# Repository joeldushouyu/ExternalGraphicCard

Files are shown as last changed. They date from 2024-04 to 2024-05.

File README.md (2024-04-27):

# ExternalGraphicCard

This Github repo contain the documentation for the USB-To-HDMI adapter(External Graphic Card) that I designed for my Senior Project.



The __USB To HDMI Adapter__(External Graphic Card) is an attempt to reproduce device that is similar to Startech's [USB32HD4k](https://www.startech.com/en-us/display-video-adapters/usb32hd4k) device that works on Linux, Ubuntu specifically. 

Currently, the device support video streaming up to 1080p at 30HZ. 

The device is compatible to most linux distribution that support by [evdi](https://github.com/DisplayLink/evdi). Currently, the device is tested and verified on Ubuntu 20.04.

When plugging the USb 3.0 Device into the host laptop and launch the C++ program, a new display monitor will be registered in OS and image data will stream out from the USb 3.0 port to the FPGA and output in HDMI signal.

**For more info**, please refer to the [user manual](Usermanual.md), [Technical Manual](TechnicalMaunaul.md), and the [Fabrication Plan Manual](./FabricationMaunal.md)

# Demonstration

## Video & Sound in Sync
[Video link](https://github.com/joeldushouyu/ExternalGraphicCard/blob/main/videoDirectory/video-sync.mp4)



## Drag window across monitors
[Video link](https://github.com/joeldushouyu/ExternalGraphicCard/blob/main/videoDirectory/drag-window-between-monitors.mp4)



## Browing  website
[Video link](https://github.com/joeldushouyu/ExternalGraphicCard/blob/main/videoDirectory/browsing-website.mp4)

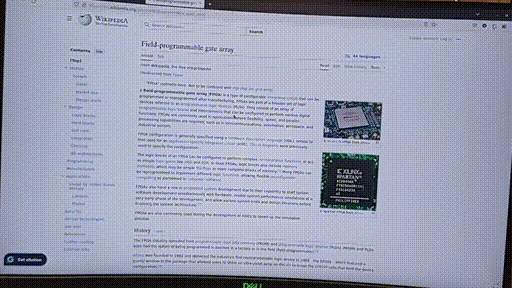
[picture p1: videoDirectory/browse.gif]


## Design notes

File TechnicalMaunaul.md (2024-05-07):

# Theory of Operation

### Figure 1: Concept Diagram
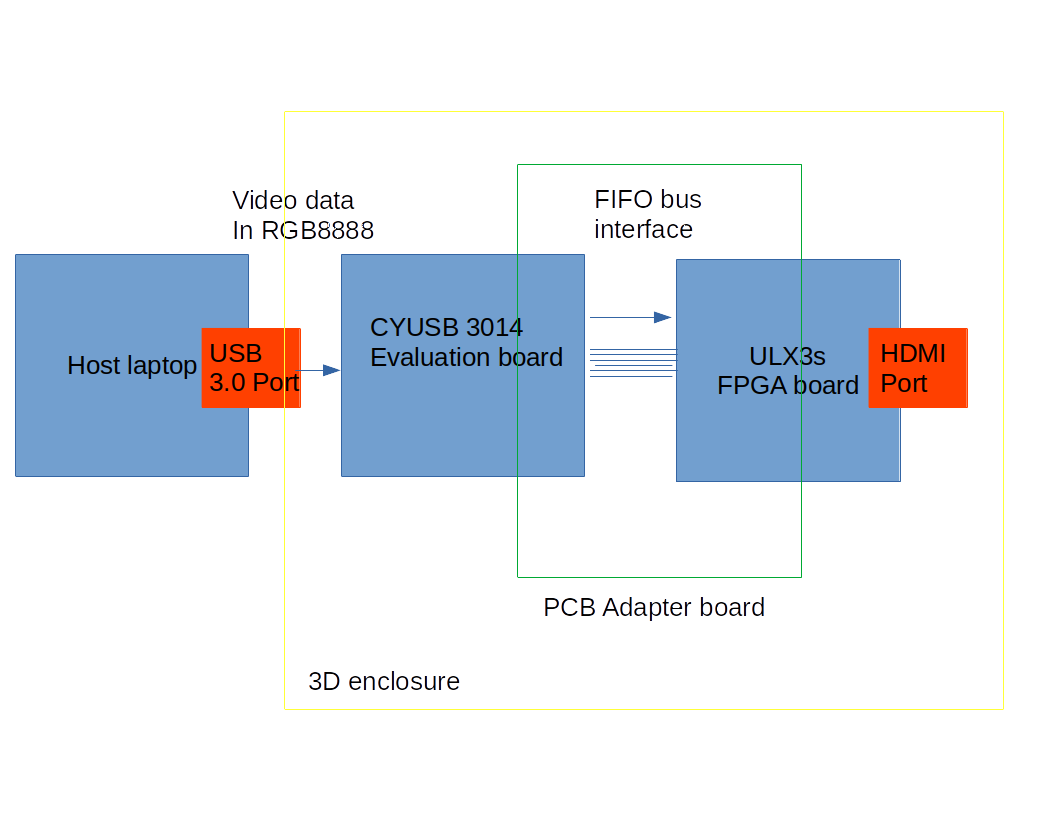
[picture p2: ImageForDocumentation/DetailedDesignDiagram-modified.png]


The device consists of 3 Major components, the __C++ program__ on the host laptop, the __CYUSB 3014 Evaluation board__, and __ULX3s__.

### C++ program on the host laptop
The C++ program on the laptop is mainly responsible for interacting with the OS to create a virtualized screen and transmit video data through USB 3.0 protocol to the CYUSB3014 device. Notably, DisplayLink, a company that sells existing USB-to-HDMI display adapters, has open-sourced part of their code to the public on Github, the [evdi](https://github.com/DisplayLink/evdi) repo. The project provides detailed documentation on their API. In addition, the repo contains a C++ based python-binding test program. 

### CYUSB3014 Device

The CyUSB3014 Device is an [evaluation board](https://www.infineon.com/cms/en/product/evaluation-boards/cyusb3kit-003/) produced by Infineon Technologies. The evaluation board consists of a CYUSB3014 programmable IC, which supports USB 3.0 communication protocol and provides a Slave Fifo Interface that allows FPGA/micro-controllers to read and write data to the fifo to interact between the USB 3.0 host device.  

 **Note**: for more information regarding the configuration below, please refer to [An65974](./ReferenceDataSheet/Infineon-AN65974_Designing_with_the_EZ-USB_FX3_Slave_FIFO_Interface-ApplicationNotes-v17_00-EN.pdf) document from Infineon Technologies. 

### Figure 2: Synchronous slave Fifo interface 
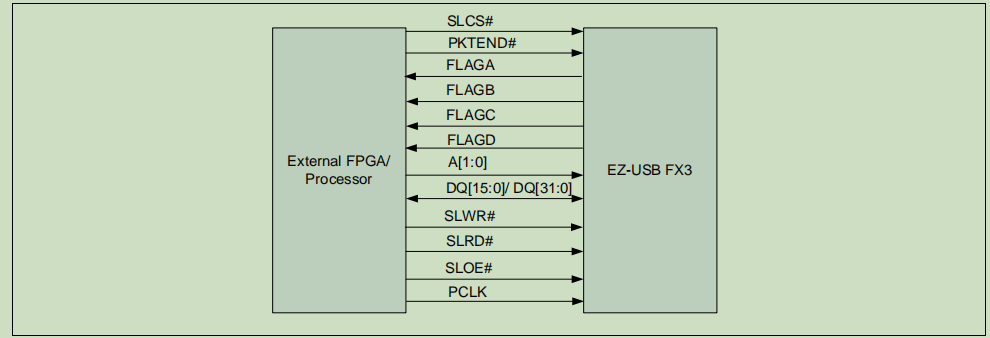
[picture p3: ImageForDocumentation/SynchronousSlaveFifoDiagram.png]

The [An65974](./ReferenceDataSheet/Infineon-AN65974_Designing_with_the_EZ-USB_FX3_Slave_FIFO_Interface-ApplicationNotes-v17_00-EN.pdf) document provides the Synchronous slave FIFO between External FPGA, as shown in Figure 2. 

In Figure 2, SLCS, SLWR, SLRD, SLOE, PKTEND, and A[1:0] are the combination of signal wires that are used by FPGA to control whether it wants to read or write to the FIFO on CyUSB3014. The PCLK is the slave FIFO interface clock from the FPGA to CyUSB3014 device, which supports up to 100MHZ. Thus, the synchronous slave FIFO mode theoretically supports up to 320Mbit/s transfer rate. For a faster transfer rate, please refer to the async fifo mode of CyUSB3014.

Moreover, FLAGA, FLAGB, FLAGC, and FLAGD are flag outputs from CyUSB3014 to indicate whether the FIFO is full/empty, or almost full/empty to FPGA. 

### ULX3s

The ULX3s is an open-sourced ECP5 [FPGA board](https://radiona.org/ulx3s/) designed by Radiona. The Ulx3s board is built around the Lattice Semiconductor ECP5-series FPGA chip and is fully supported by the latest open-source toolchains. The board consists of 56 pins (28 differential pairs), 2 USB 2.0 ports, 11 LEDs, and a Digital video (GPDI General-purpose Differential Interface). For more detail regarding to the board, please refer to the [information](https://www.crowdsupply.com/radiona/ulx3s) on CrowSupply.

## How it all work together

### Figure 3 Verilog Design
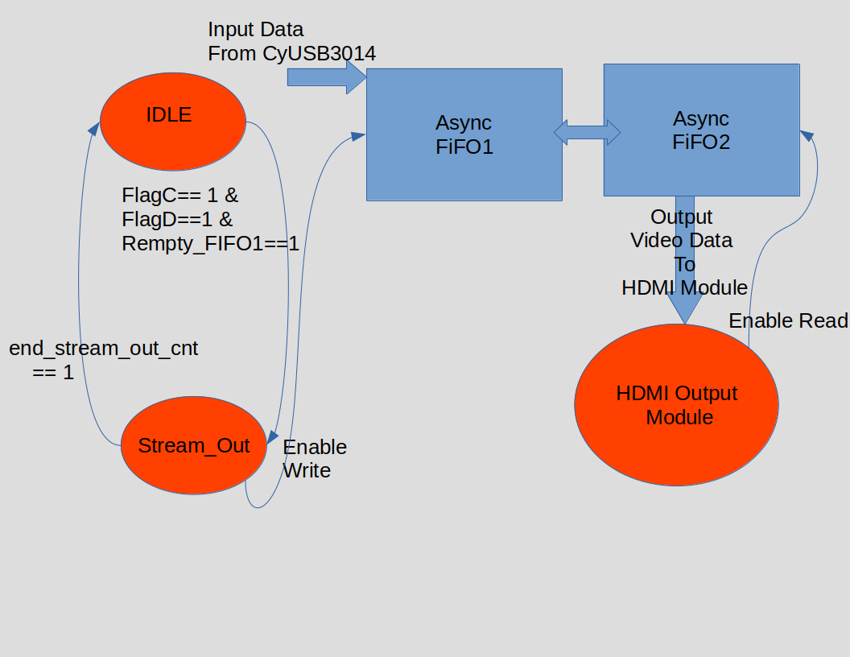
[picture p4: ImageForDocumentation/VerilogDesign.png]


For the [C++ program](https://github.com/joeldushouyu/evdi/blob/userProgram/userProgram/main.cpp) that run on host laptop, I simply __forked__ the evdi repo, **extracted** the C++ framework that was used in the python-binding test program, create a c++ program that calls the function in the __extracted__ C++ framework.
Given the evdi library implemented a non-blocking file descriptor under the hood, I simply added a [usleep](https://github.com/joeldushouyu/evdi/blob/userProgram/userProgram/main.cpp#L211) function call in the main event-handler loop for interacting with evdi library. In addition, considering the importance of smooth video data streaming and the **huge** I/O delay in using the __synchronous__ api of [libusb](https://github.com/libusb/libusb), I decide to use the __asynchronous__ API of libusb and start new [thread](https://github.com/joeldushouyu/evdi/blob/userProgram/userProgram/main.cpp#L205) in the program for handling libusb callback-event. To sync between the new frame data generated by the evdi [event-loop](https://github.com/joeldushouyu/evdi/blob/userProgram/userProgram/main.cpp#L210) and the frame data sent off by libusb [event-loop](https://github.com/joeldushouyu/evdi/blob/userProgram/userProgram/main.cpp#L187), similar to the famous **[Produce-consumer problem](https://en.wikipedia.org/wiki/Producer%E2%80%93consumer_problem)**, I added a mutex lock and a deque in [Card.h](https://github.com/joeldushouyu/evdi/blob/userProgram/userProgram/Card.h#L69-L70). Essentially, both the evdi [event-handler](https://github.com/joeldushouyu/evdi/blob/userProgram/userProgram/Card.cpp#L214) and libusb [callback](https://github.com/joeldushouyu/evdi/blob/userProgram/userProgram/main.cpp#L103) need to acquire the __exclusive__ mutex lock when adding or retrieving frame data from the dequeue.

Assuming the CyUSB3014 device is pre-configured into synchronous slave-fifo mode, upon receiving USB data from the host laptop, the Cyusb3014 IC pushes the data to the internal buffer and notifies the ULX3s FPGA board by toggling both FLAGC and FLAGD wire (for more detail, please see the configuration part of CyUSB3014 board). 

The [Verilog program](https://github.com/joeldushouyu/ulx3s-misc/tree/doubleFIFOImplementation/examples/dvi) is forked and modified the existing [HDMI video output Verilog demo](https://github.com/emard/ulx3s-misc/tree/master/examples/dvi). The overall structure of the verilog code is shown in Figure 3. In the Verilog program, I modified the [Async fifo](https://github.com/joeldushouyu/async_fifo/tree/doubleFifoBuffer) project to create a double FiFo. The first FIFO is configured to be [4096 word size](https://github.com/joeldushouyu/ulx3s-misc/blob/doubleFIFOImplementation/examples/dvi/top/top_usbtest.v#L890) and the second FIFO is configured to be [64-word size](https://github.com/joeldushouyu/ulx3s-misc/blob/doubleFIFOImplementation/examples/dvi/top/top_usbtest.v#L891). The FPGA start out in __IDLE__ state with both FIFO empty. Once the CyUSB3014 board toggle FLAGC and FLAGD wire that indicate available data and FIFO1 indicate is empty, the FPGA goes to **Stream_Out** mode to read 4096 words from CyUSB3014 and write to FIFO1. After the data passes from FIFO1 to FIFO2 and indicates data available to __HDMI Output Module__, the __HDMI Output Module__ enables the __Enable Read__ wire and start reading video data from FIFO2 and convert to HDMI signal.

**Note** Given CyUSB3014 is set up to 32 bit, the __word size__ should be configured to 32 bit. However, the __word size__ is currently configured to [16 bit](https://github.com/joeldushouyu/ulx3s-misc/blob/doubleFIFOImplementation/examples/dvi/top/top_usbtest.v#L888) due to issue with the PCB board design. For more info, please refer to the __Notes in "Schematics and Drawings"__ section.

**Note** Currently, there is a [bug](https://github.com/dpretet/async_fifo/pull/13) I found in the async_fifo after adding [parameters for threshold value](https://github.com/dpretet/async_fifo/pull/11). Once the PR I submitted is merged, I will need to re-merge the [doube-fifo branch](https://github.com/joeldushouyu/async_fifo/tree/doubleFifoBuffer) that I used for this project with the [main branch](https://github.com/dpretet/async_fifo) 

# Schematics and Drawings

### Schematic 1: Circuit Schematic
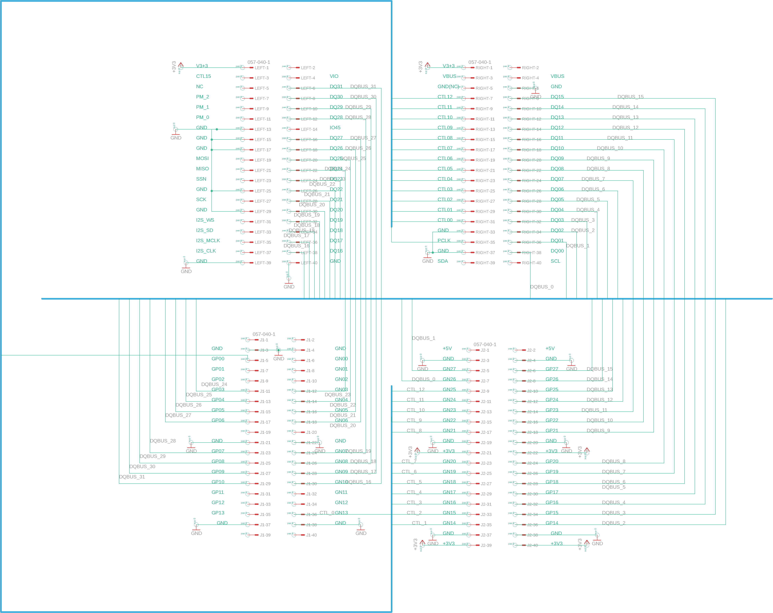
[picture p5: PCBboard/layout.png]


### Schematic 2: Top Layer PCB
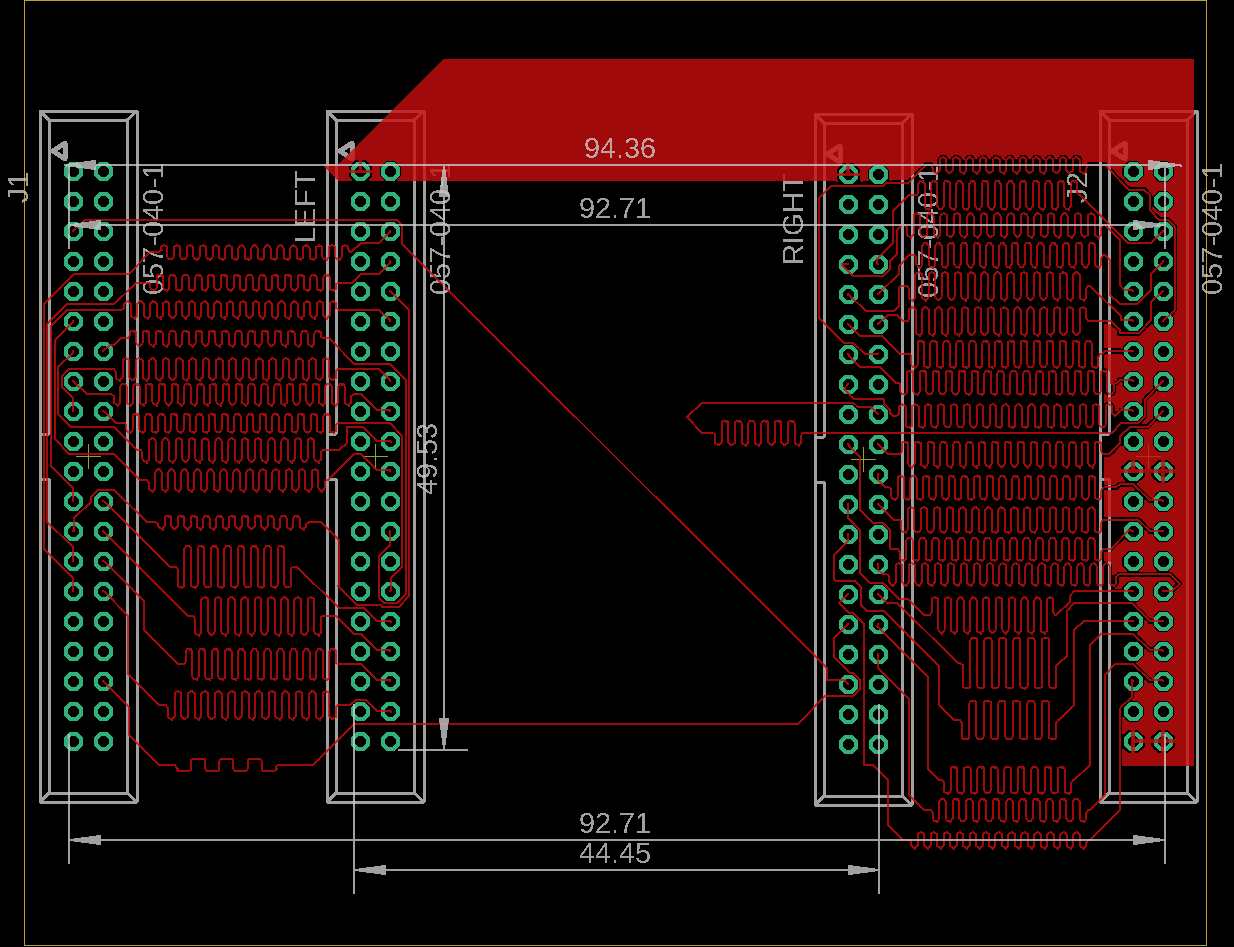
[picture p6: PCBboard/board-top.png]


### Schematic 3: Bottom Layer PCB
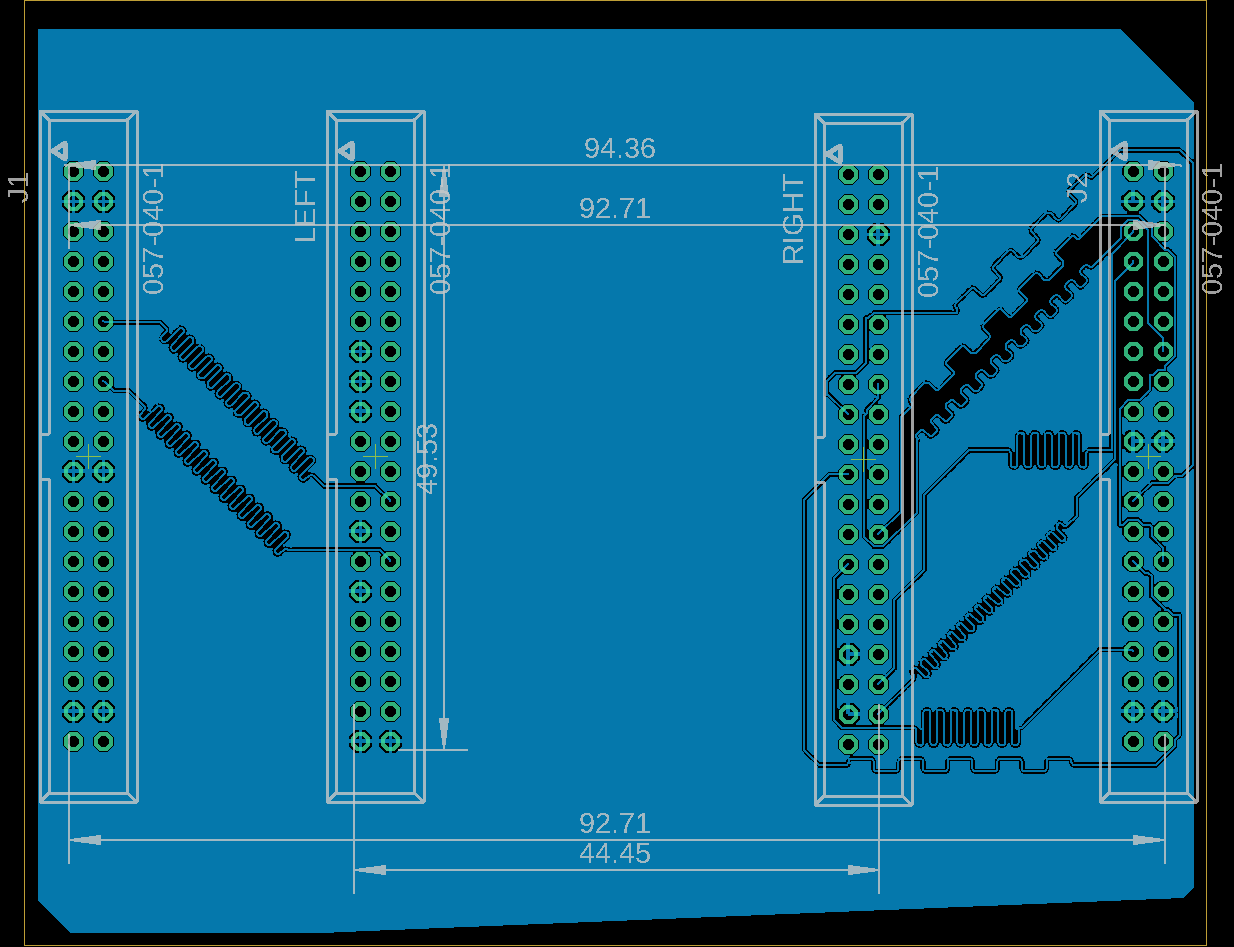
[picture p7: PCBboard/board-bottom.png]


**Problem 1** Due to the incorrect measurement, the current PCB layout board only fits to __16 bit bus wide__ of Cyusb3014. 

**Problem 2** The PCB board design did not consider the possible trace length difference between the I/O pins on __ULX3s__. Thus, data will be distorted at clock frequency __higher__ than __60MHZ__.

# Bill of Materials
|Part Name| Part Number | Vendor Name | Web Address| Note|
|---|---|---|---|-----|
|ULX3s | CS-ULX3S-01 | Mouser Electronics| https://www.mouser.com/ProductDetail/Radiona/CS-ULX3S-01?qs=hWgE7mdIu5Sz6R%252BJENFe0A%3D%3D| Could get the 12F version for a cheaper price|
|PCB board connector pin| B08DVGCTKT | Amazon| https://www.amazon.com/dp/B08DVGCTKT?psc=1&ref=ppx_yo2ov_dt_b_product_details| |
|CyUSB3014 Evaluation board | 	CYUSB301x | Mouser Electronics|  https://www.mouser.com/ProductDetail/727-CYUSB3KIT-003| |
|PCB Conversion Board | Standard PCB/PCBA | JLCPCB | https://jlcpcb.com | Could potentially produce the board with other online sellers, see detail in __Manufacture__ section |

# Prerequisite & Manufacturing Details

## 1. Install software for building the verilog project
Setup Yosys and tools for compiling the ULX3s by following the README.md guide in [oss-cad-suite-build](https://github.com/YosysHQ/oss-cad-suite-build).
**Note** You might want to consider adding the following line into your bashrc file to save you the headache of sourcing the environment at your terminal. 
```bash 
export PATH="<extracted_location>/oss-cad-suite/bin:$PATH"
```

Also, add the [vhdlv](https://github.com/ldoolitt/vhd2vl) project by
    1. clone and build the vhdlv project
    2. add the build result to __PATH__ variable in .bashrc, just like above.
## 2. Setup the evid library
### Step 1
Option 1 (**preferred** & tested version): Install the correspond linux driver by following the user manual from Displaylink for [Ubuntu](https://www.synaptics.com/products/displaylink-graphics/downloads/ubuntu) or [Other Linux Distribution](https://support.displaylink.com/knowledgebase/articles/679060)

Option 2: Clone the [evdi](https://github.com/DisplayLink/evdi) and follow the [install guide](https://github.com/DisplayLink/evdi/issues/413)

### Step 2
Clone  My Forked branch that contains modified [User Program code](https://github.com/joeldushouyu/evdi). 

**NOTE:** The modified User program code is in the **userProgram** branch,**not in** the __main__ branch!

### Step 3
Add the following line into __.bashrc__ or any __shell program__ you are using.
```sh
    export LD_LIBRARY_PATH=$LD_LIBRARY_PATH:/PathOFCloneEvdiProject/evdi/library
```
## 3. Setup CyUSB3014 device

**NOTE** Currently, the GPIFII tool from Cypress **only works on Windows platform**, thus I have to configure Cypress in the VMWare that runs Windows 11.

For More __detail__ on loading configured image to CyUSB3014, please refer to [AN76405](./ReferenceDataSheet/Infineon-AN76405_-EZ-USB_FX3_FX3S_boot_options-ApplicationNotes-v12_00-EN.pdf) documnt, **page 28**.

### step 1: install driver
Download and install the [windows driver](https://softwaretools.infineon.com/tools/com.ifx.tb.tool.ezusbfx3sdk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) for CyUSB3014 device.

### step 2: Configure Wire mapping in GPIF II designer
To configure the FlagA,B,C, and D flag wires on CyUSB 3014, one needs to use __GPIF II designer__.

**Open** GPIF II designer and open the existing **sync_slave_fifo_2bit** example
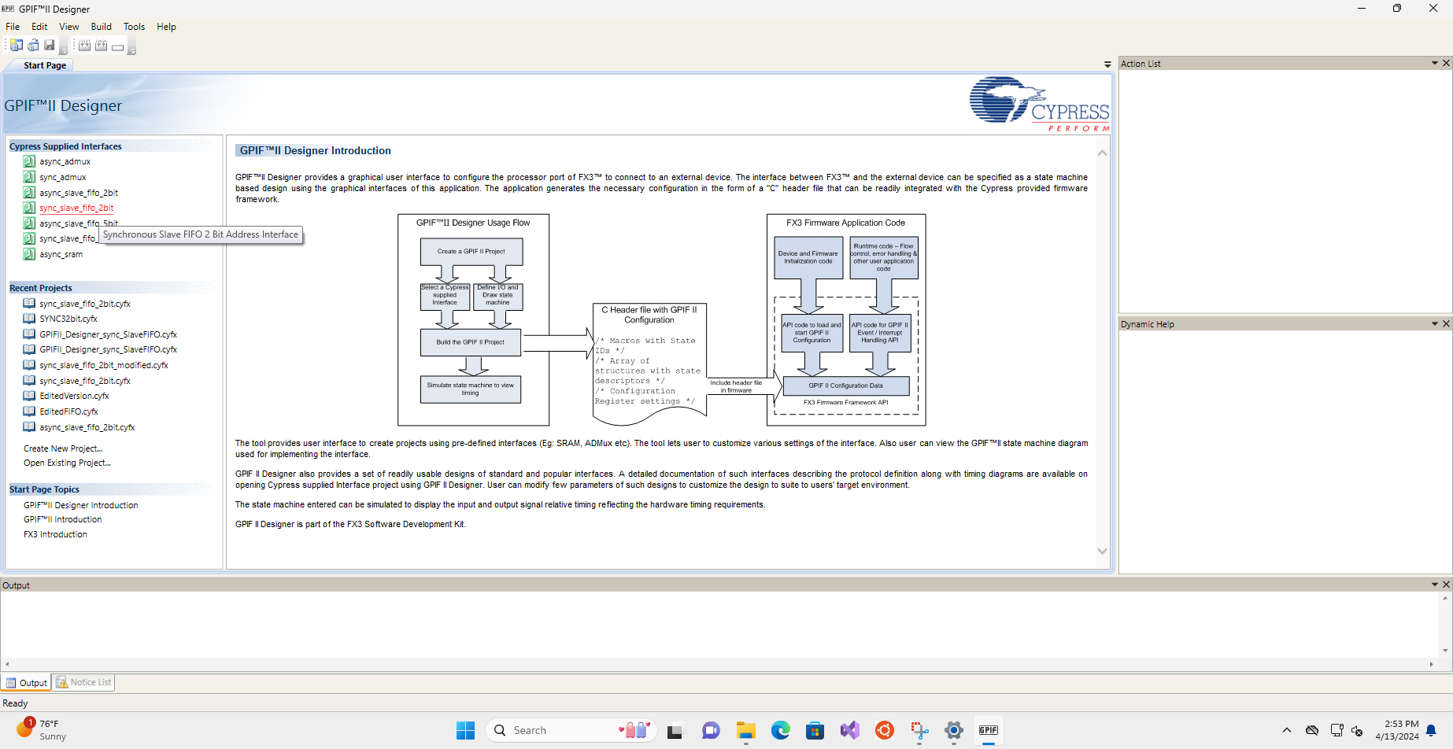
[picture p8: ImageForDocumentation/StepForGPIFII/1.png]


Choose **File->Save Project As Editable** to save a new copy of the project. **Close** the current GPIF II project and reopen the __new__ copy of the project.
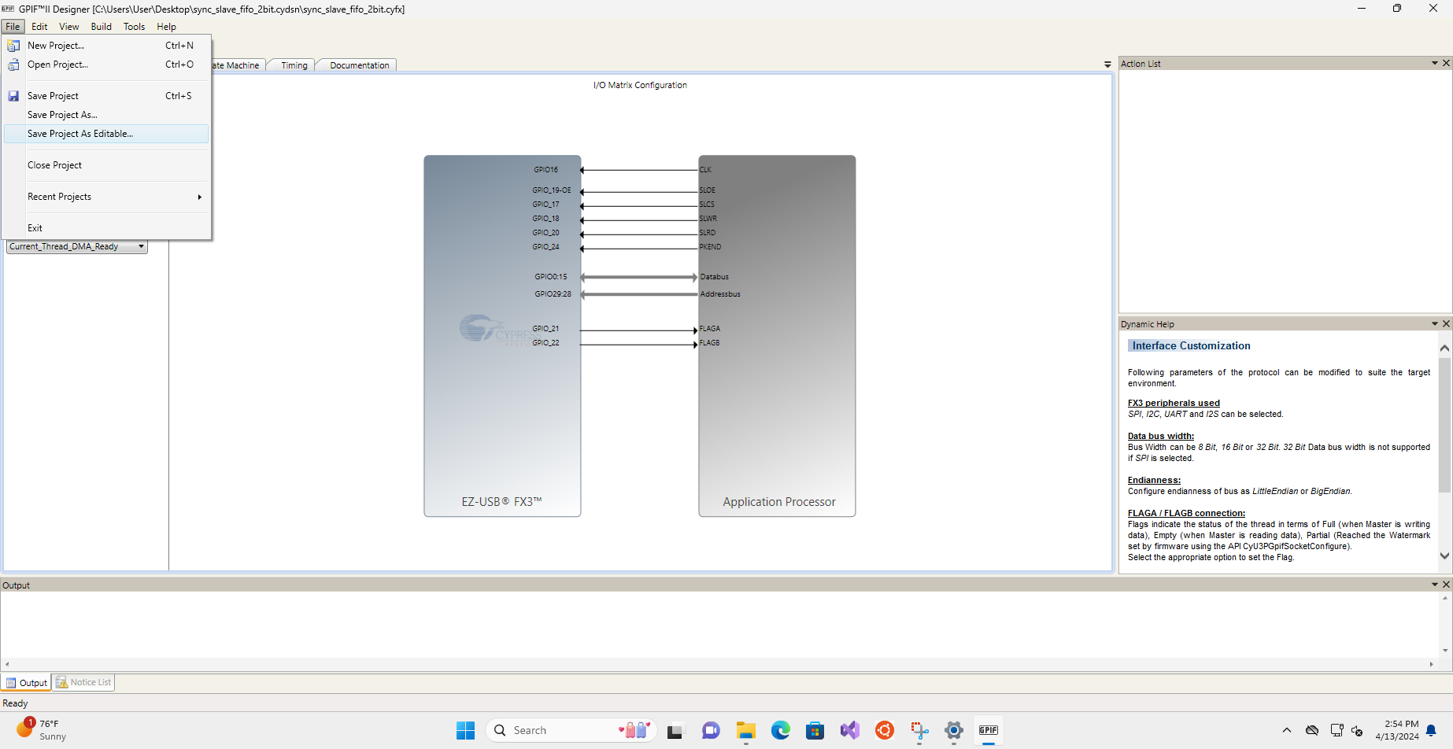
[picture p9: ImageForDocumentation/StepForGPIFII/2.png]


Modify the settings under __Interface Settings__ to add all 4 FLAG wires to the pin-mapping.
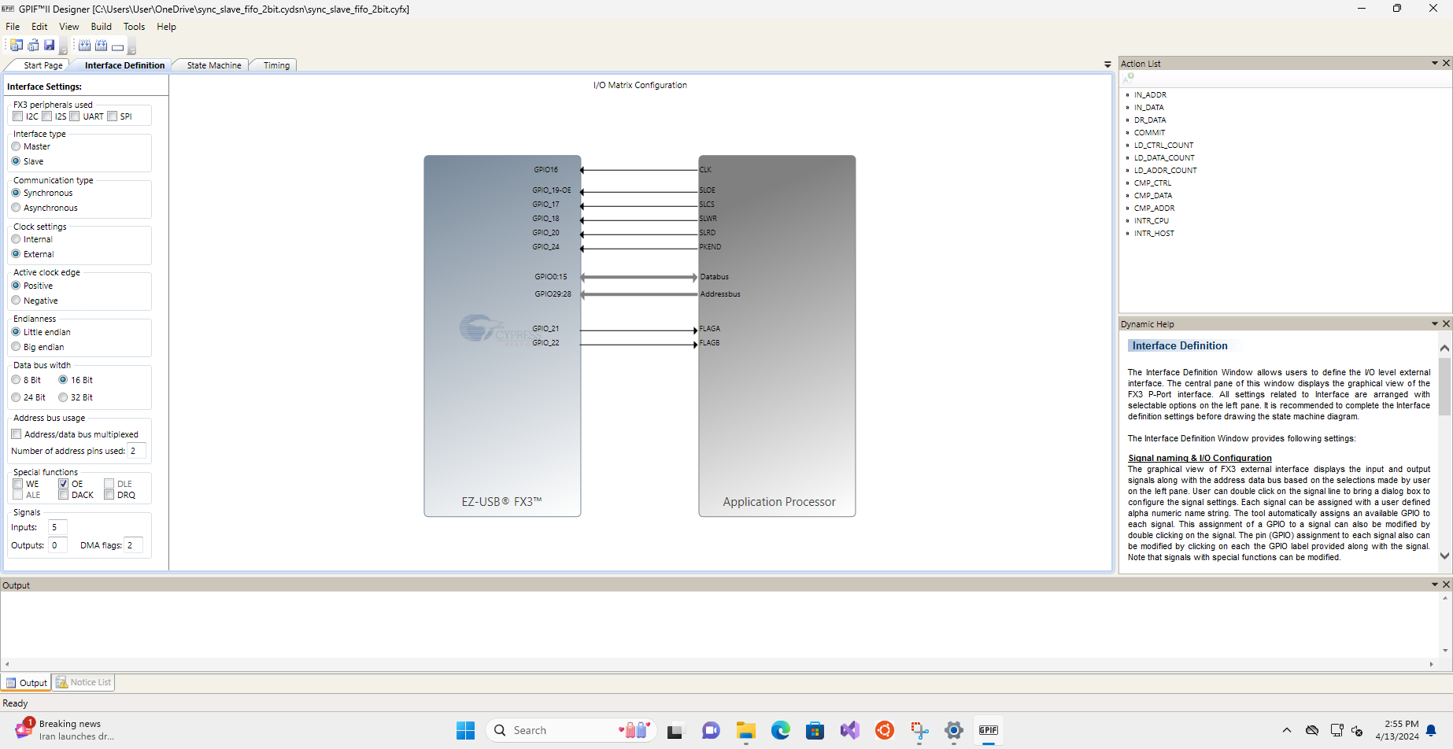
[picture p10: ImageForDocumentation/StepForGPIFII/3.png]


**Right click** on FlagA in the __I/O MatrixConfiguration__ and select **DMA Flag Settings**
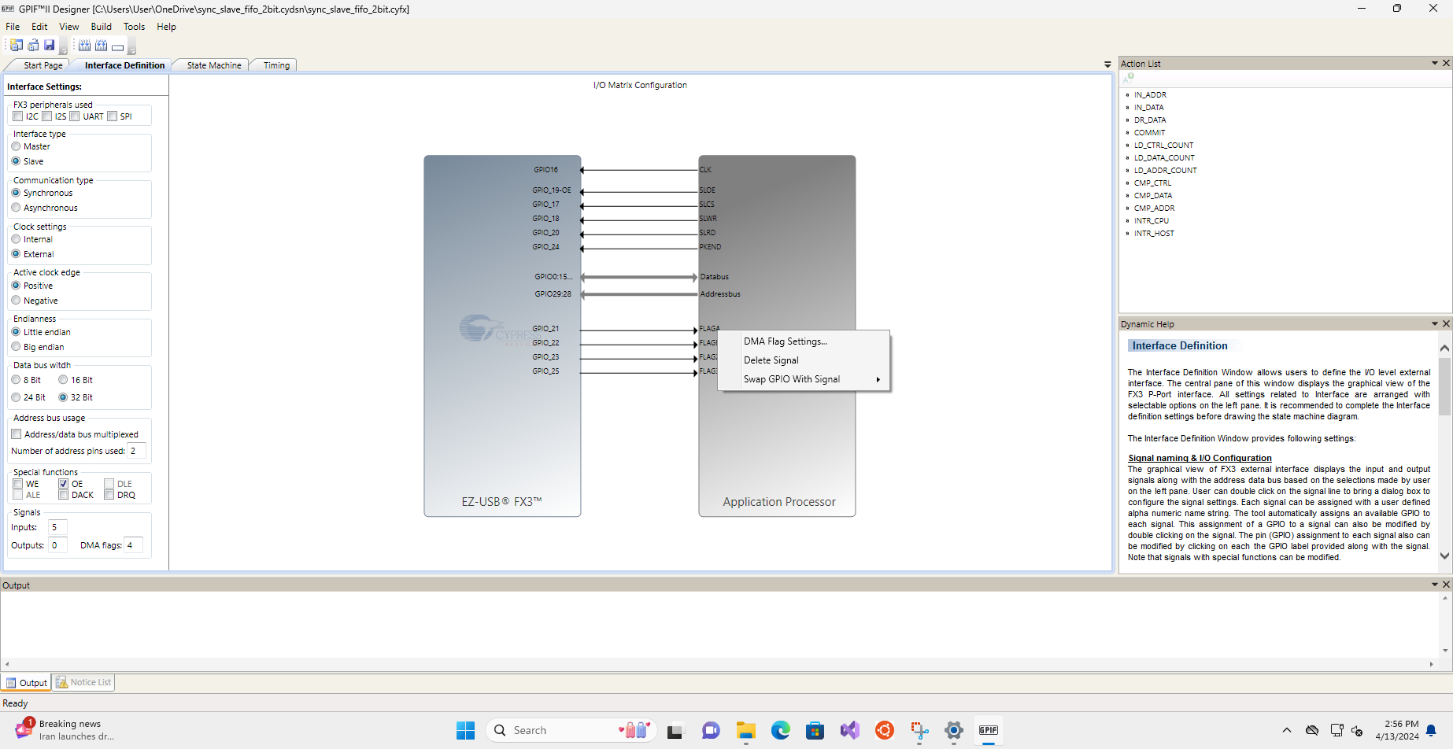
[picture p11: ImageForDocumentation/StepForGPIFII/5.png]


Configure the setting for **FlagA** to be Full flag dedicated to thread0 for Stream_IN data transfer, see more on Page 33 of [An65974](./ReferenceDataSheet/Infineon-AN65974_Designing_with_the_EZ-USB_FX3_Slave_FIFO_Interface-ApplicationNotes-v17_00-EN.pdf) document.
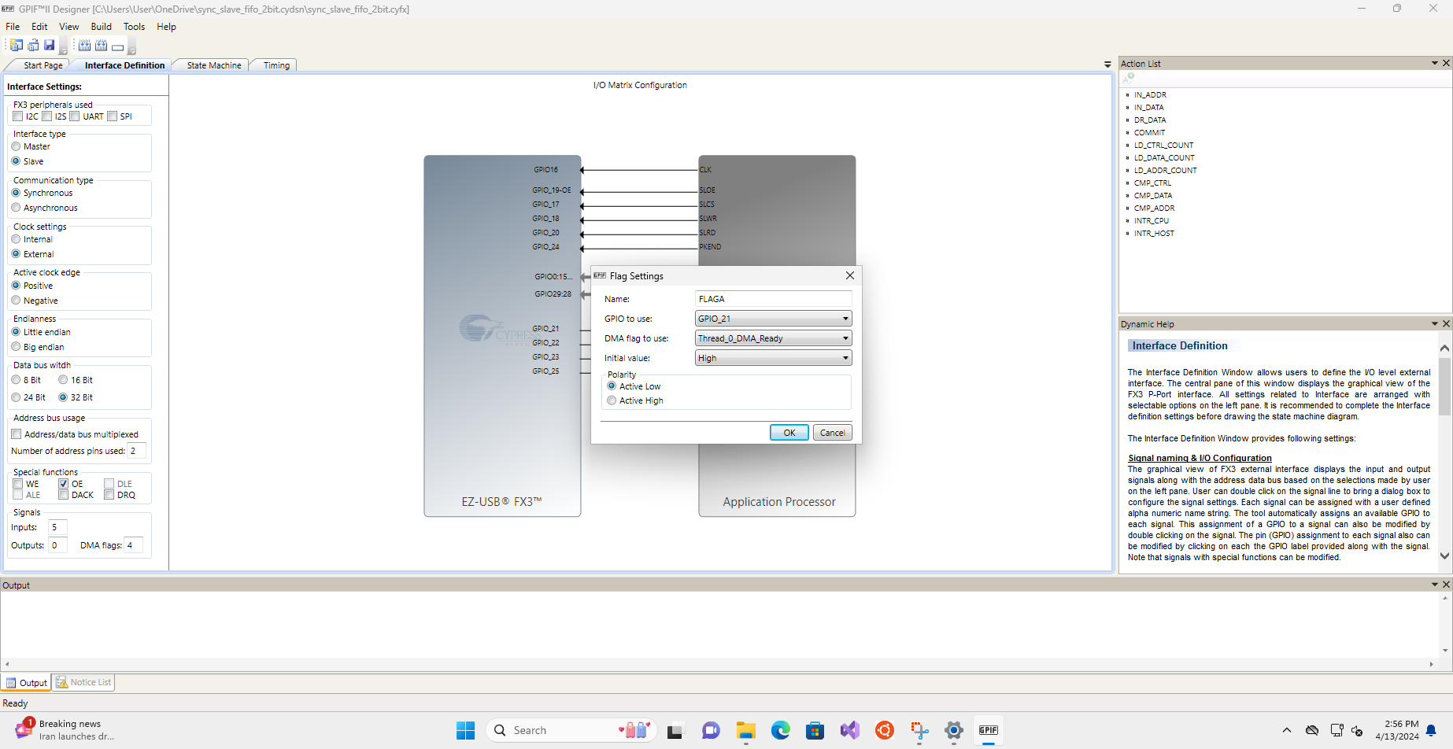
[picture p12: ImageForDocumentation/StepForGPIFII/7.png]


Configure the setting for **FlagB** to be Partial Flag with watermark dedicated to thread0.
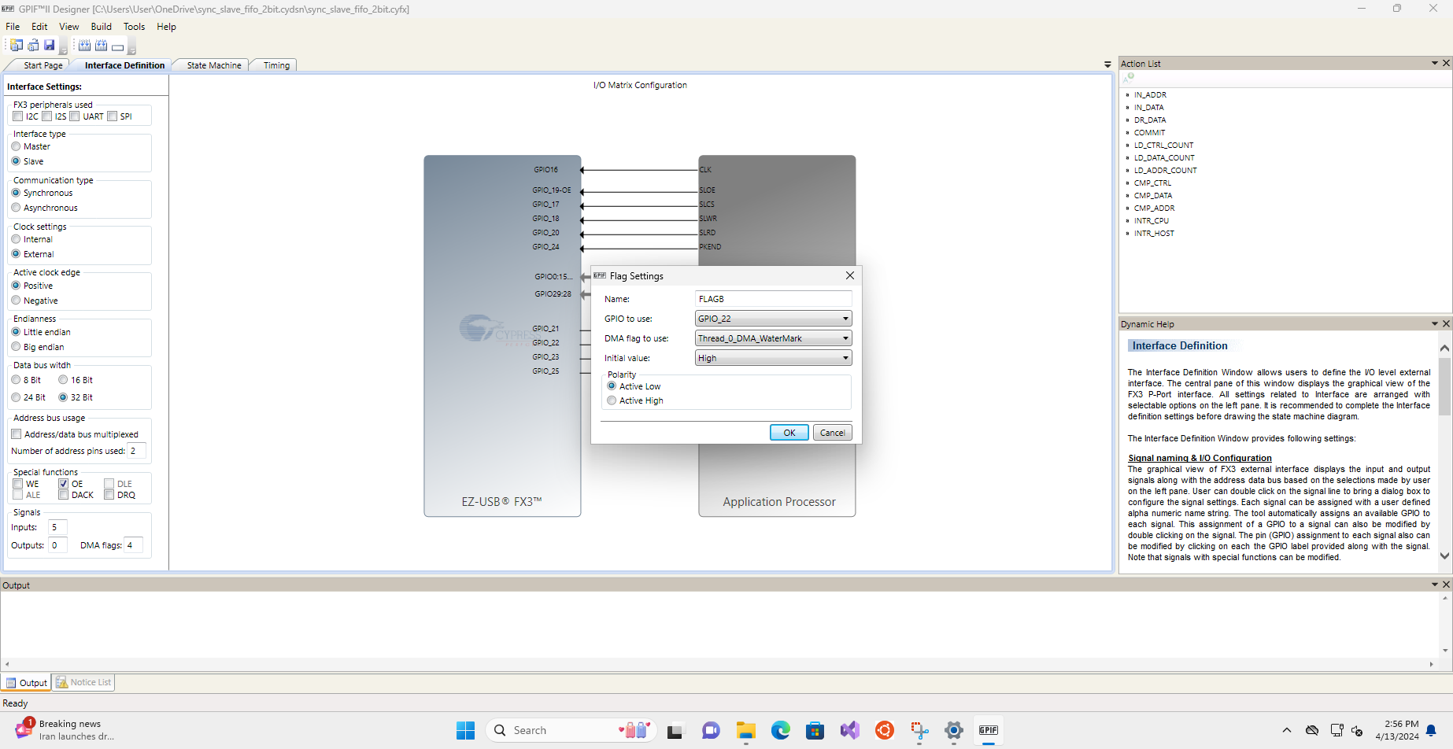
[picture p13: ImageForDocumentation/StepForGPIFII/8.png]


Configure the setting for **FlagC** to be Full flag dedicated to thread 3 for Stream_Out data transfer/
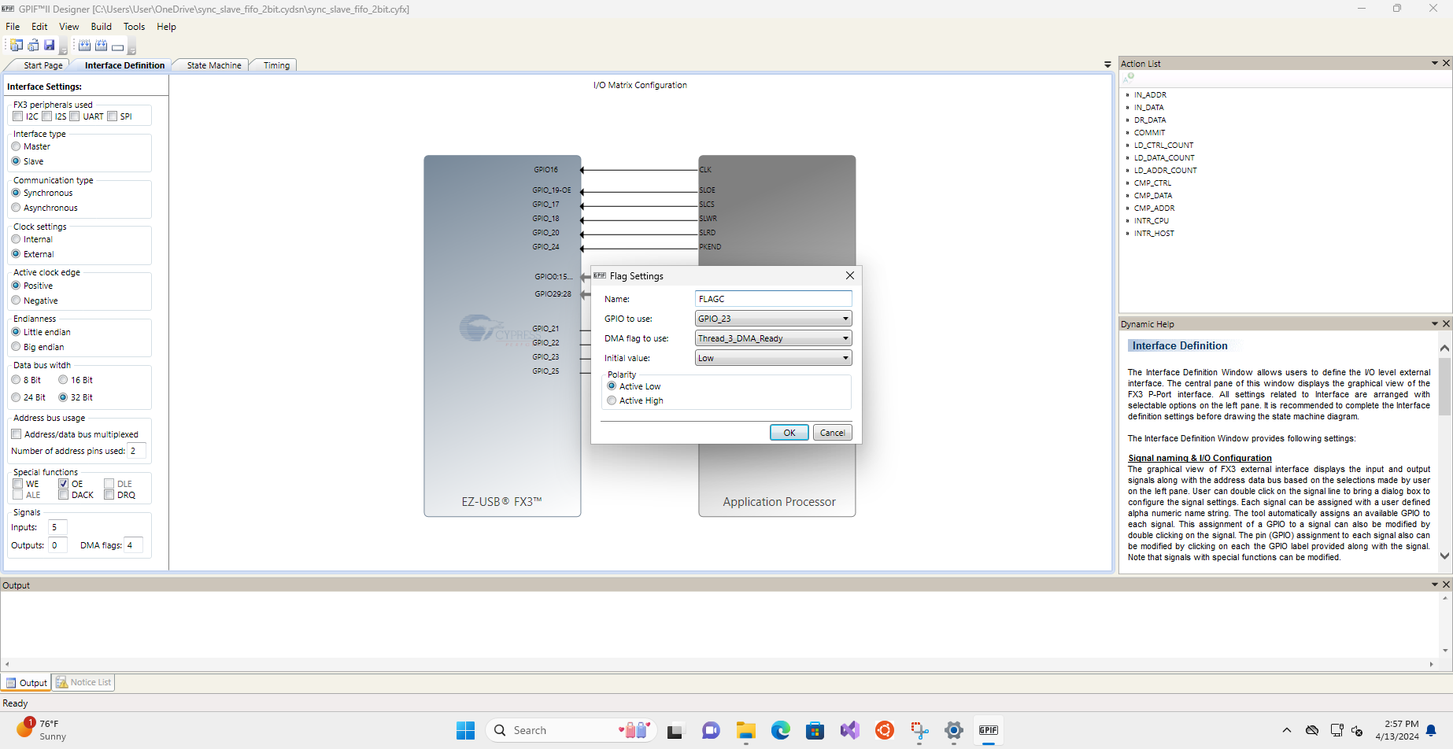
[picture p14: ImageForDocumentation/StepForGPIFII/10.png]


Configure the setting for **FlagD** to be Partial Flag with watermark dedicated to thread3.
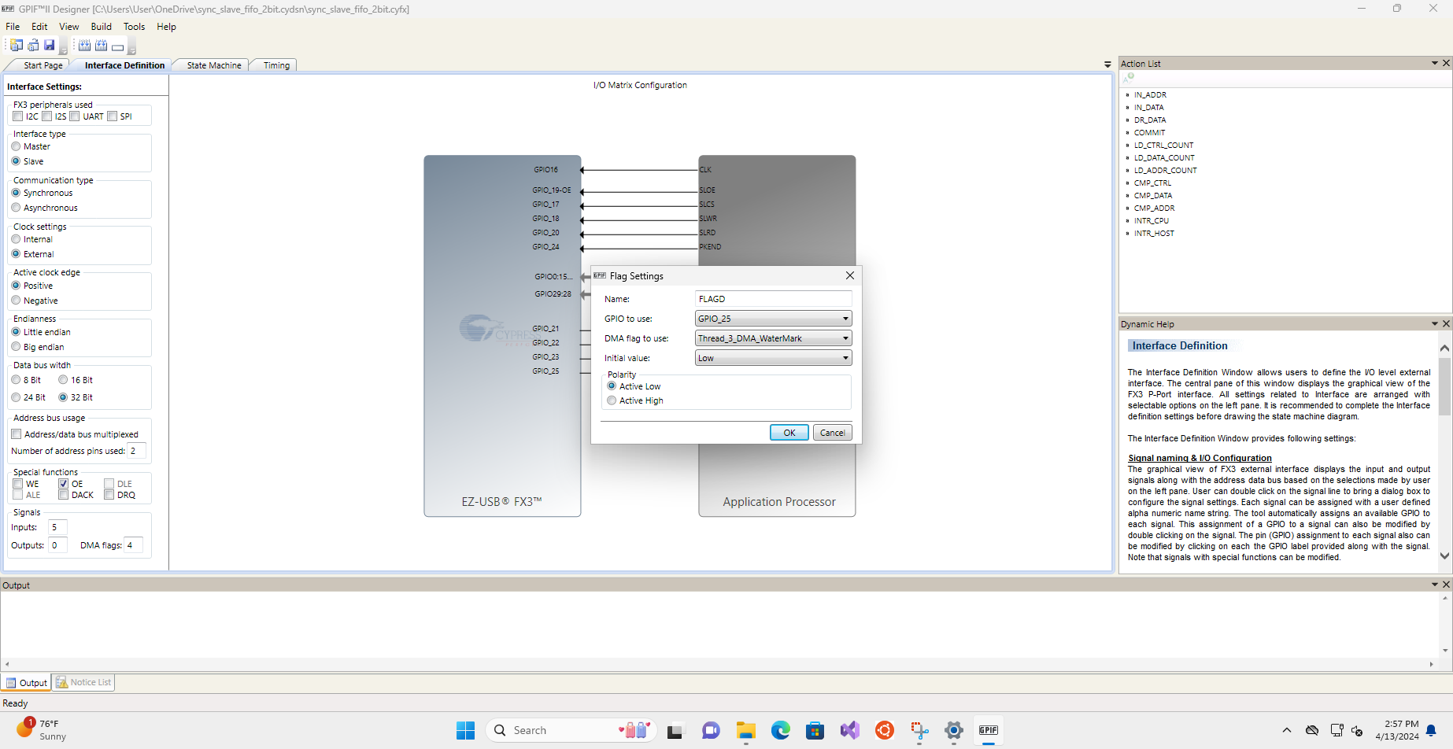
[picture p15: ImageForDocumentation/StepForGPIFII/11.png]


Choose **Build->Build Project** to build the project.

The build job will generate a **cyfxgpif2config.h** file inside the project folder. The content of the file should closely match the existing [cyfxgpif2config.h](./CypressFx3Configuration/my_slave.cydsn/cyfxgpif2config.h). **Note**: The content of the file could vary due to different firmware version in the feature, but the overall I/O mapping MACRO should be the same (Unless there is a design change in CyUSB3014 IC and board layout).

### step 3: Import & build CyUSB3014 Project
Navigate to the folder where the firmware of CyUsb3014 is installed on Windows. For my case, the firmware is installed in __C:\Program Files (x86)\Cypress\EZ-USB FX3 SDK\1.3\firmware__. 

Copy the __slfifosync__ in ***C:\Program Files (x86)\Cypress\EZ-USB FX3 SDK\1.3\firmware\slavefifo_examples*** to a different location. 

**Copy** the **cyfxgpif2config.h** from __GPIF II Designer__ build above into the **newly copied** __Slfifosync__ folder.   
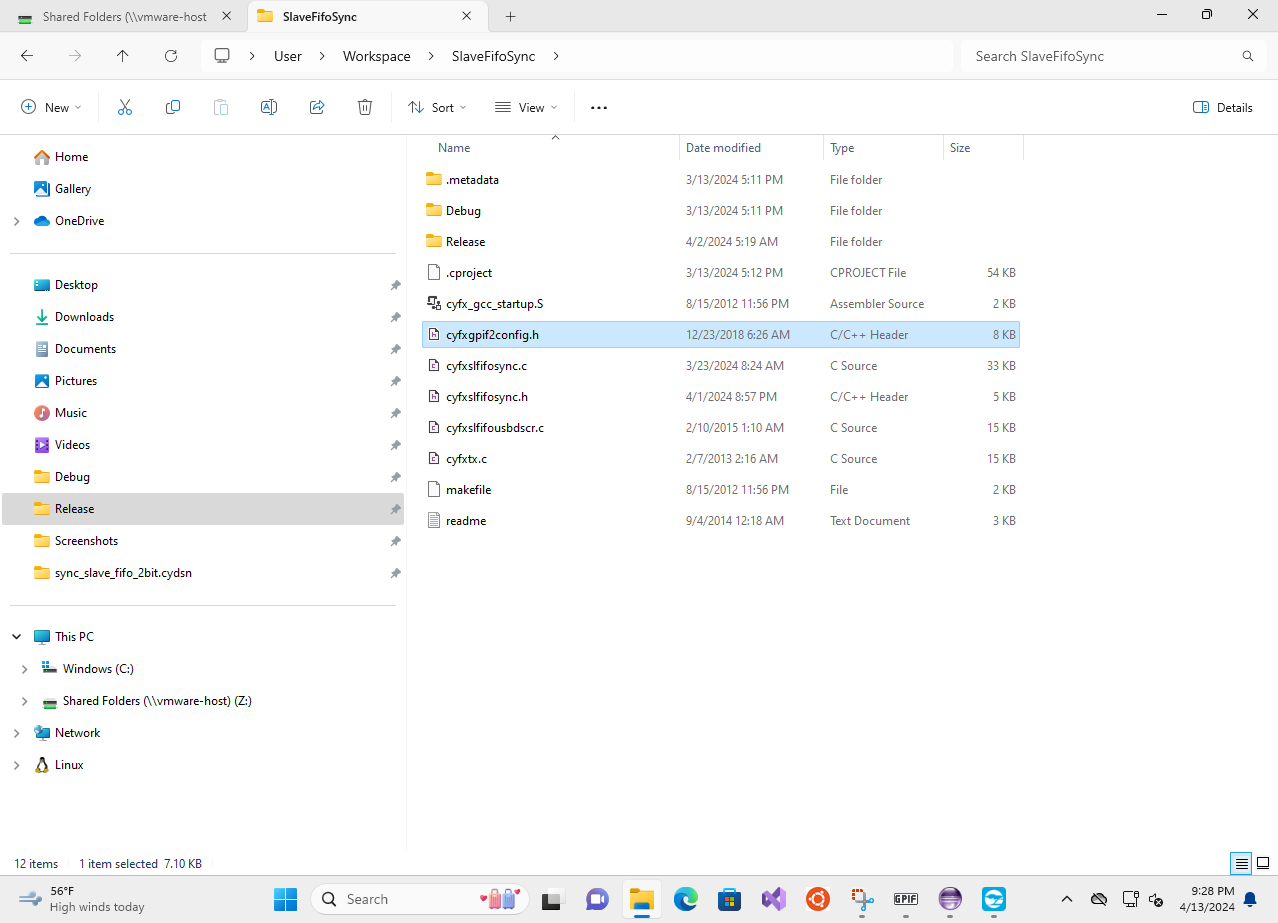
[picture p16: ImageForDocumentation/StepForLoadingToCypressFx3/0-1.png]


__Launch__ ***EZ USB SUITE***, choose **File->Import** to import the newly copied __slfifosync__ version.
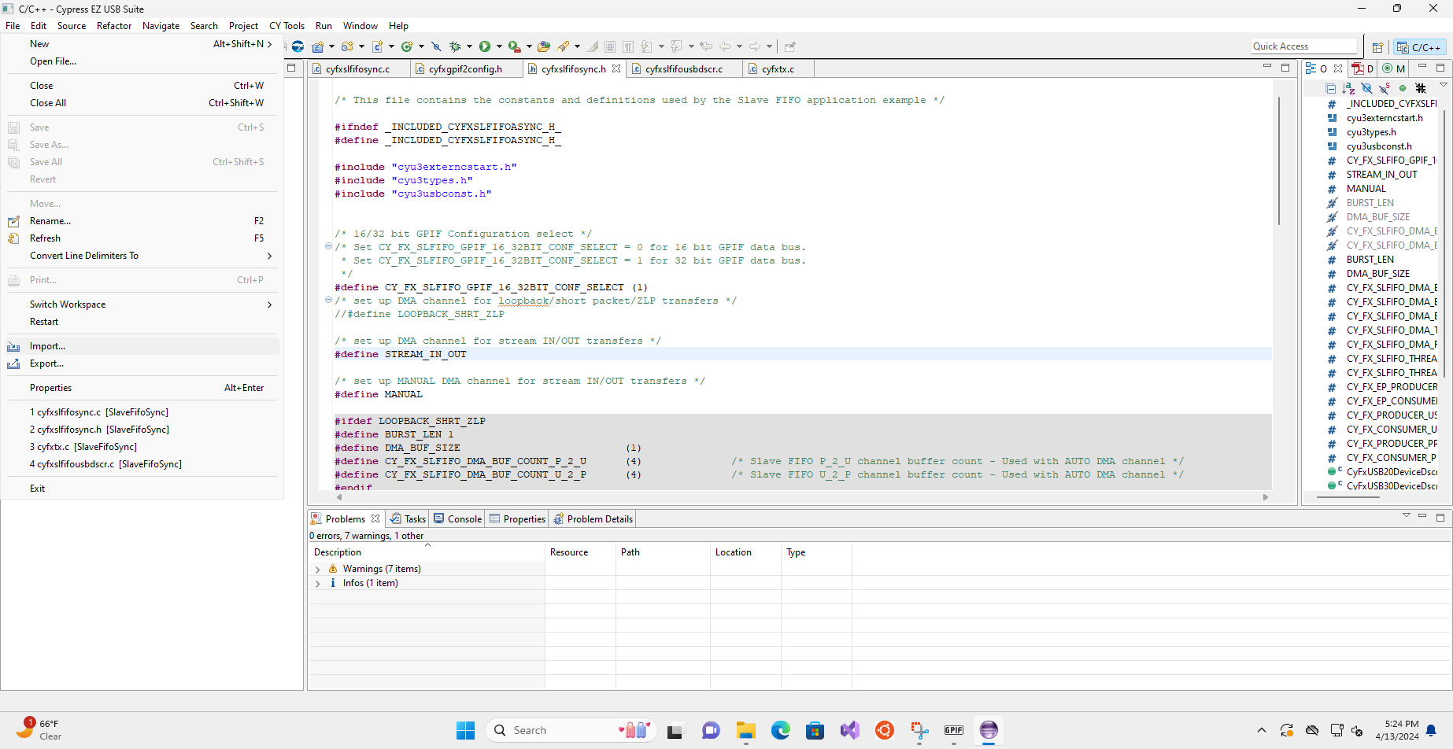
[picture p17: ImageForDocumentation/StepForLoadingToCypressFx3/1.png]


In __cyfxslfifosync.c__ file, set the watermark for Thread0 to 4 and Thread 3 to 3. Doing so allows FlagB to turn from high-to-low immediately after the FIFO is full for stream_In and FlagD to turn from high-to-low immediately after the FIFO is empty for Stream_Out. For more detail regarding to the __Watermark__ configuration, please refer to __Section 9.3__ of [An65974](./ReferenceDataSheet/Infineon-AN65974_Designing_with_the_EZ-USB_FX3_Slave_FIFO_Interface-ApplicationNotes-v17_00-EN.pdf) document.
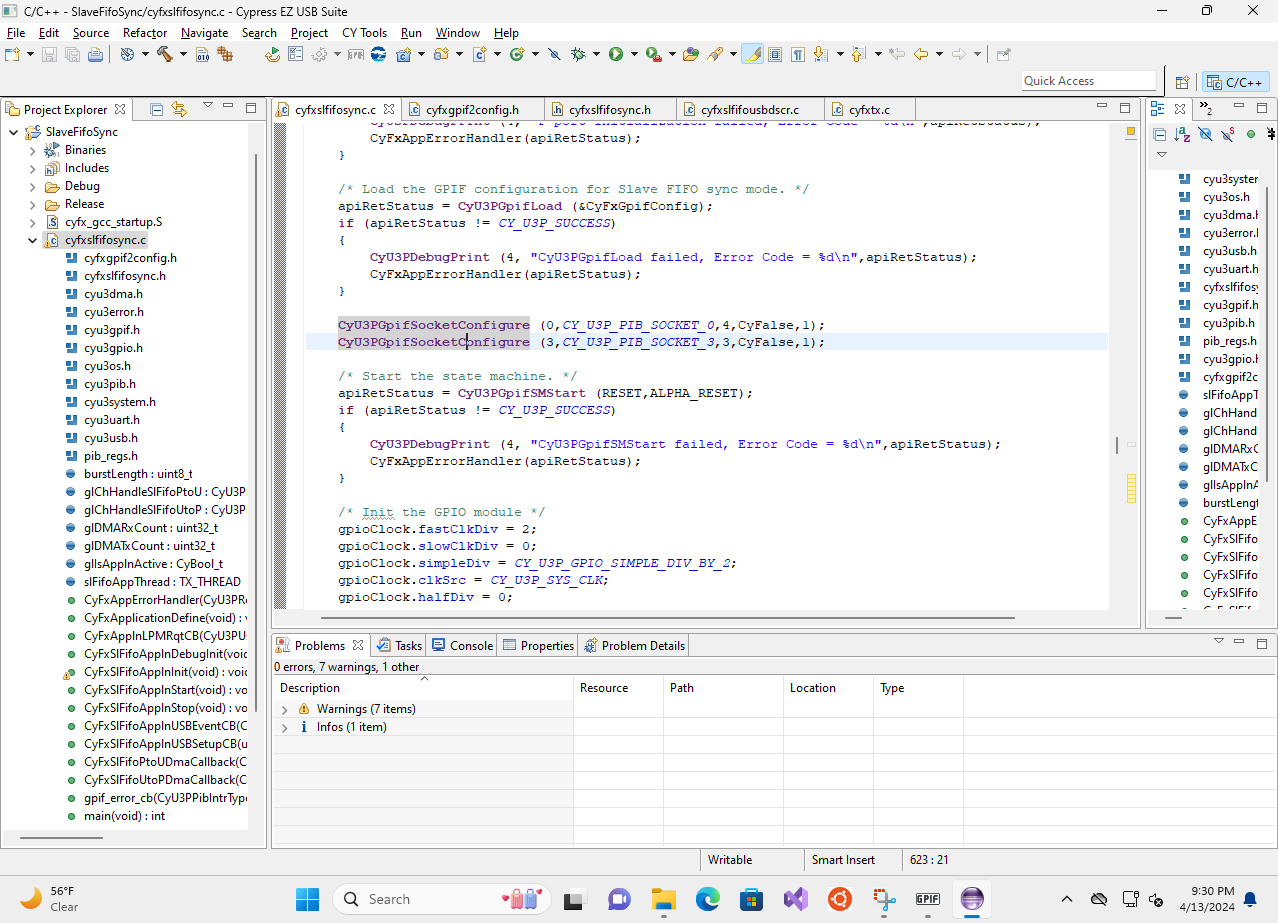
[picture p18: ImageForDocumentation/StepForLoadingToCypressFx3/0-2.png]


**Add** the following code to __cyfxslfifosync.h__ to configure the FIFO size for both stream_In and stream_Out. 
```c++
/* set up DMA channel for stream IN/OUT transfers */
#define STREAM_IN_OUT
// code in between ........

#ifdef STREAM_IN_OUT
#define BURST_LEN 16
#define DMA_BUF_SIZE						 (16)
/* Slave FIFO P_2_U channel buffer count */
#define CY_FX_SLFIFO_DMA_BUF_COUNT_P_2_U      (2)
/* Slave FIFO U_2_P channel buffer count */
#define CY_FX_SLFIFO_DMA_BUF_COUNT_U_2_P 	  (10)
#endif
```
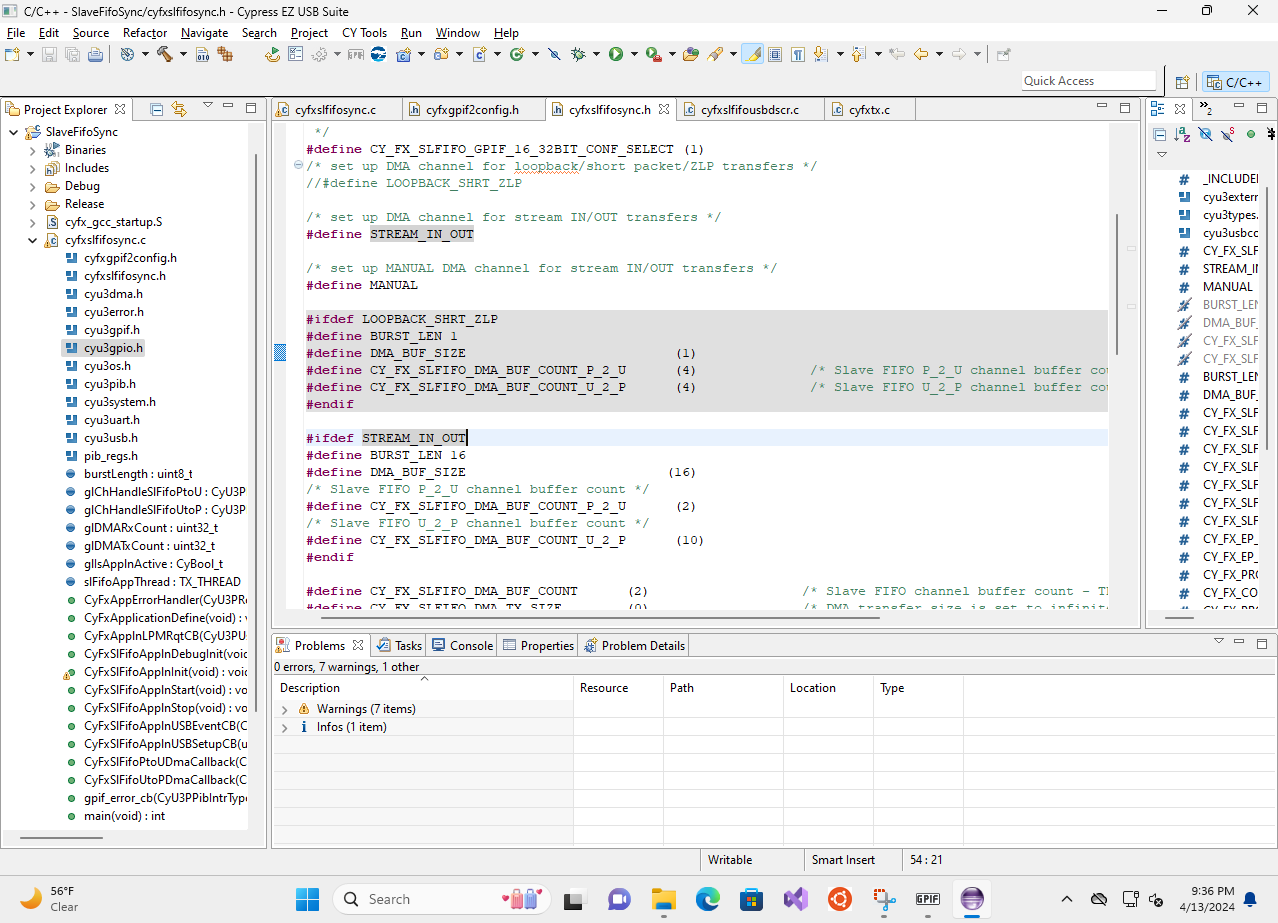
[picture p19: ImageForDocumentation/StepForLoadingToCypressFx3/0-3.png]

**Note** Given the fact that for our application, we are ___only configuring___ CyUSB 3014 board in stream_out mode( read from CyUSB3014 to FPGA) and only use stream_in mode for ___debug___, we assign a larger size on the ***stream_out*** fifo. Thus, we allocate a bigger FIFO size for stream_out compare to the instruction in [An65974](./ReferenceDataSheet/Infineon-AN65974_Designing_with_the_EZ-USB_FX3_Slave_FIFO_Interface-ApplicationNotes-v17_00-EN.pdf) document. For more detail, please refer to **page 36** of [An65974](./ReferenceDataSheet/Infineon-AN65974_Designing_with_the_EZ-USB_FX3_Slave_FIFO_Interface-ApplicationNotes-v17_00-EN.pdf) document.

By now, the content of __slfifosync__ should be nearly identical to the [existing configuration ](./CypressFx3Configuration/SlaveFifoSync/). **Note**: The content of the file could vary due to different firmware versions in the feature, but the overall code should be similar.

Choose **Release** build mode and build the
[project](./CypressFx3Configuration/my_slave.cydsn/).
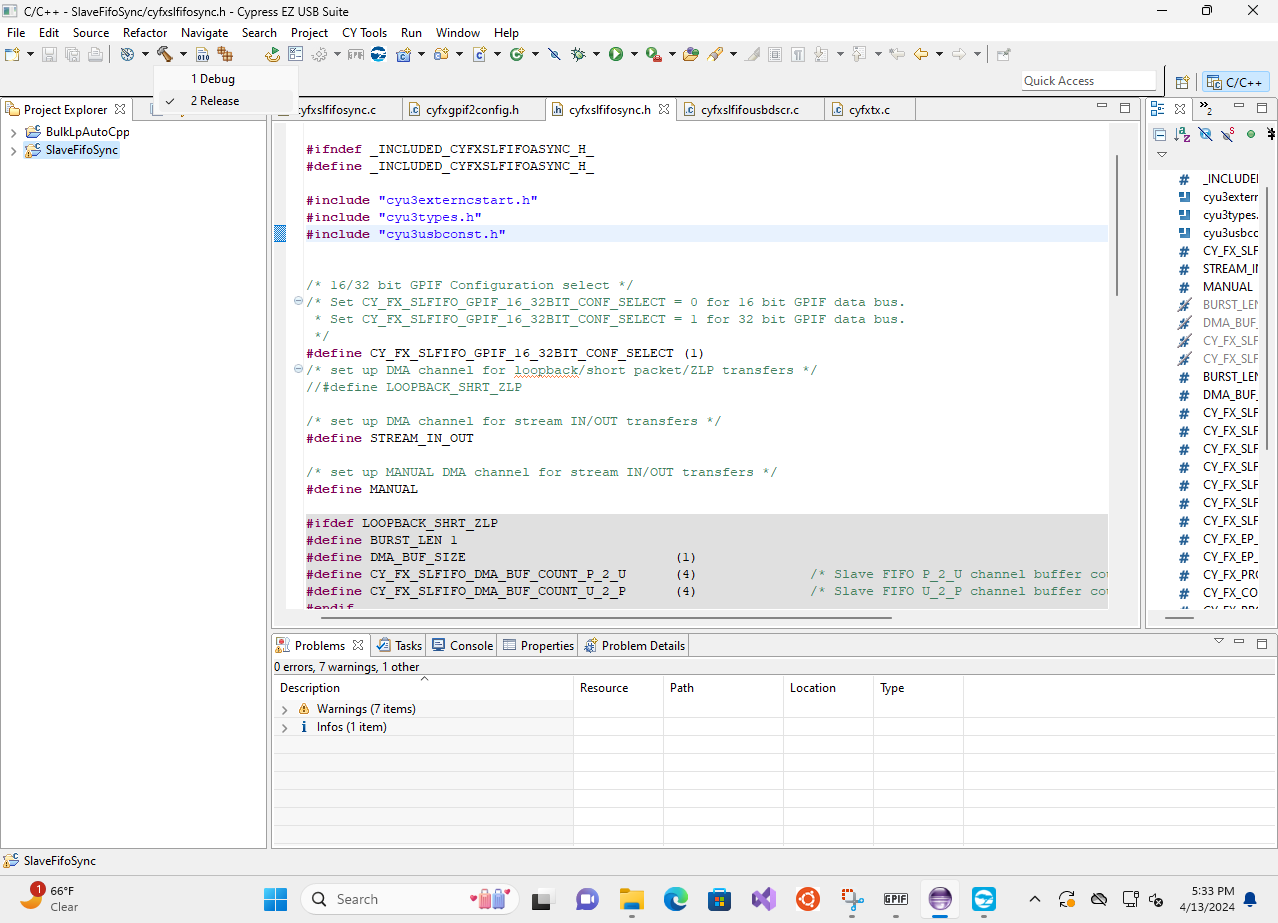
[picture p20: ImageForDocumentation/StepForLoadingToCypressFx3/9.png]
.

By this time, a __SlaveFifoSync.img__ should exist under the [Release](./CypressFx3Configuration/SlaveFifoSync/Release/) sub-folder.

### step4 : Load build image to CyUSB3014 in I2C mode

Configure CyUSB3014 device into PMODE by placing the Jumper Cap on __J4__ and a Jump wire that connects **PM_1** and **V3P3** pins on the board.


Plug the CyUSB3014 device into the USB 3.0 port and launch __USB Control Center__.

Select **Program->Fx3->I2C EEPROM** 
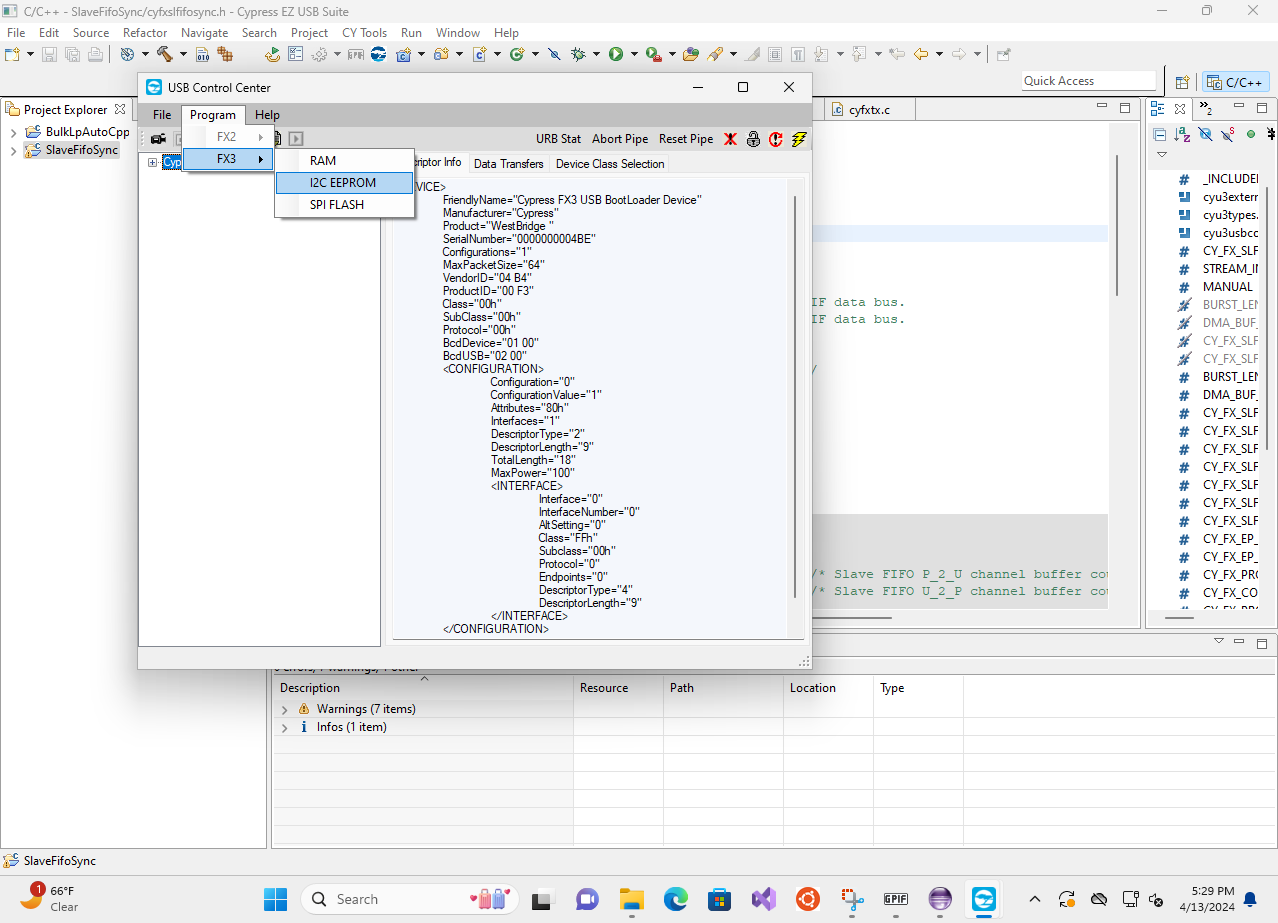
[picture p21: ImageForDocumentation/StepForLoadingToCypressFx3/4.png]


Navigate to find  __SlaveFifoSync.img__  under the [Release](./CypressFx3Configuration/SlaveFifoSync/Release/) sub-folder.
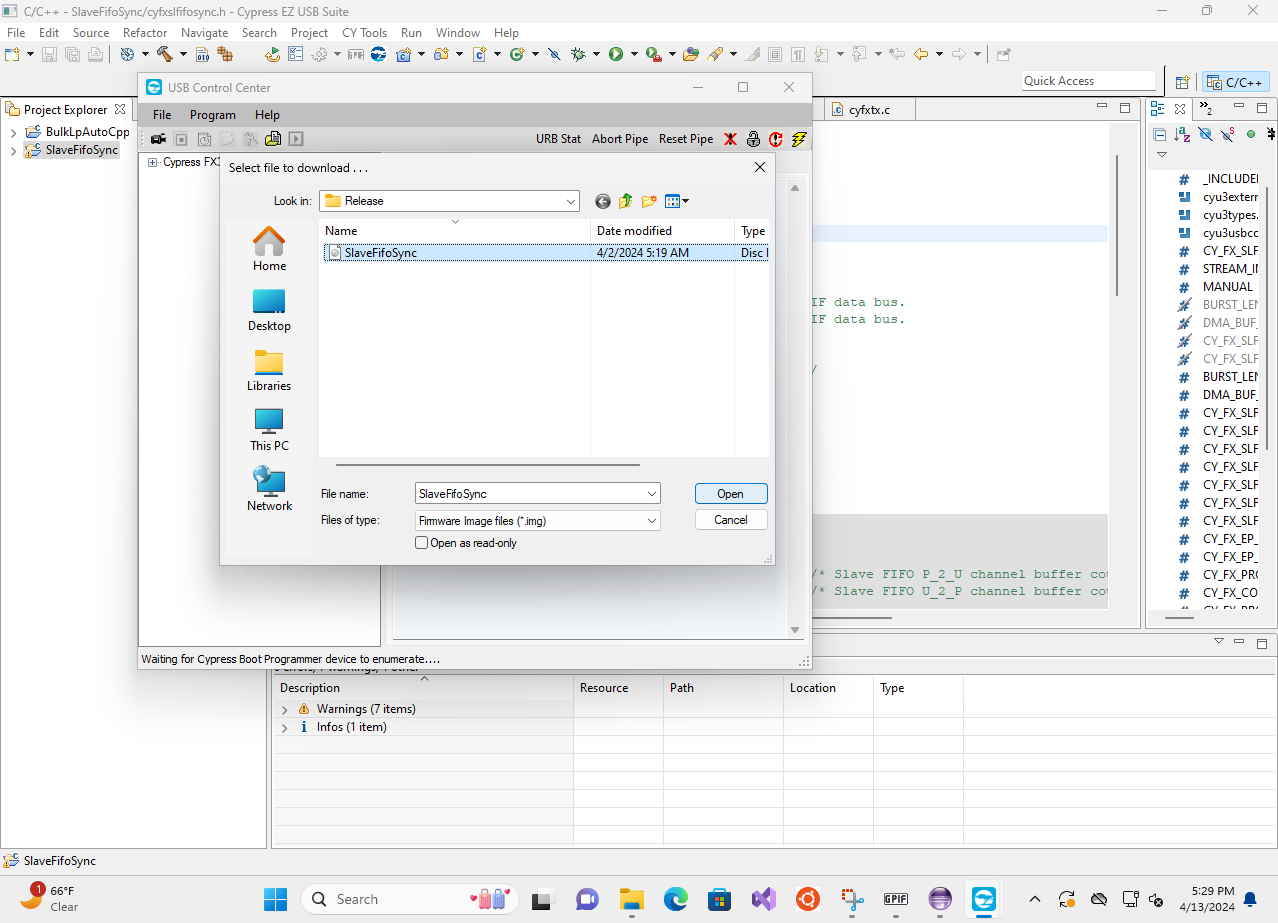
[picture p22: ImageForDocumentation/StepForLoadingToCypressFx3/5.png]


Press **Open** and the software will start loading __SlaveFifoSync.img__ into CyUSB3014 device. This process might take about **5 minute.**

**Once finished** loading __SlaveFifoSync.img__, **unplug** CyUSB3014 from the laptop and **remove both** the ***jumper cap and jumper wire***.

## 4. Compile the verilog program
### step 1: Clone modified ulx3s-misc project
Clone My Forked Branch of [ulx3s-misc](https://github.com/joeldushouyu/ulx3s-misc). 

**NOTE** The current verilog code is in the __doubleFIFOImplementation__ branch. Be sure to check out the [__doubleFIFOImplementation__](https://github.com/joeldushouyu/ulx3s-misc/tree/doubleFIFOImplementation) branch after cloning.

### step 2 : Initialize the async_fifo git submodule
***cd*** into the directory of ***/ulx3s-misc-colonePath/examples/dvi*** and run the following command in the terminal.

**Note** Currently, I submit an [PR](https://github.com/dpretet/async_fifo/pull/13) that is supposed to fix the Bug that I found using the [async_fifo](https://github.com/dpretet/async_fifo). Once the PR got merged, I will need to sync the [doubleFifoBuffer](https://github.com/joeldushouyu/async_fifo/tree/doubleFifoBuffer) with the main branch.

```bash
    git submodule init
    git submodule 
```
### step 3 : Build the FPGA project
Modify the [FPGA_SIZE](https://github.com/joeldushouyu/ulx3s-misc/blob/doubleFIFOImplementation/examples/dvi/makefile.trellis#L5) in the Makefile base on the version of ULX3s you have. 

Compile the programming by running the following command in the terminal.
```bash
make
```

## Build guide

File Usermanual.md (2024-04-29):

# Introduction

The __USB To HDMI Adapter__(External Graphic Card) is an attempt to reproduce a device that is similar to Startech's [USB32HD4k](https://www.startech.com/en-us/display-video-adapters/usb32hd4k) device that works on Linux, Ubuntu specifically. 

Currently, the device supports video streaming up to 1080p at 30HZ. 

The device is compatible to most linux distribution that support by [evdi](https://github.com/DisplayLink/evdi). Currently, the device is tested and verified on Ubuntu 20.04.

# Safety
Given the device is only powered by the USB 3.0 port (around 5 Watt), the device does not introduce the risk of electrical shock and injury in any situation. 

However, please keep the device **away** from water split and  **do not** use the device in any wet conditions. Doing so could damage the device!

# Description & Terminology
1. [C++ user program](https://github.com/joeldushouyu/evdi/tree/userProgram/userProgram) - C++ code that utilize [evdi](https://github.com/DisplayLink/evdi) to create a virtual screen in the Linux-based OS.
2. Host laptop - The laptop/computer that runs the C++ program that generates video data.
3. CyUSB3014 - A Cypress [USB 3014 Evaluation board](https://www.infineon.com/cms/en/product/evaluation-boards/cyusb3kit-003/) produced by Infineon. Left component in Figure 1 and Figure 2.
4. ULX3s - An open-sourced ECP5 [FPGA board](https://radiona.org/ulx3s/) designed by Radiona. The right component in Figure 1 and Figure 2

5. PCB Conversion board - A customized design double-layer PCB board that connects the pins between CyUSB3014 and ULX3s. Moreover, the board utilizes the Vcc pins on CyUSB3014 to power the ULX3s device.  The middle component of Figure 1 and Figure 2.

#### Figure 1: Front View of Component
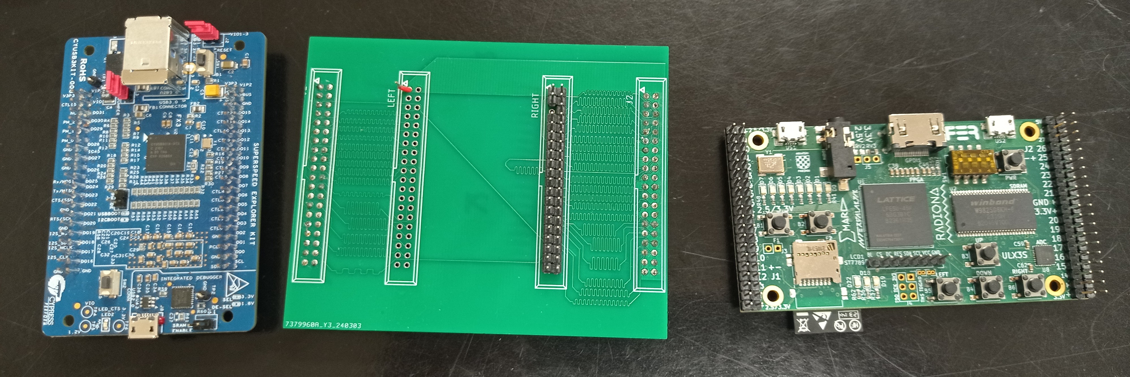
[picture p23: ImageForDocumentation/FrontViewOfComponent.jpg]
Front View

#### Figure 2: Back view of the Component
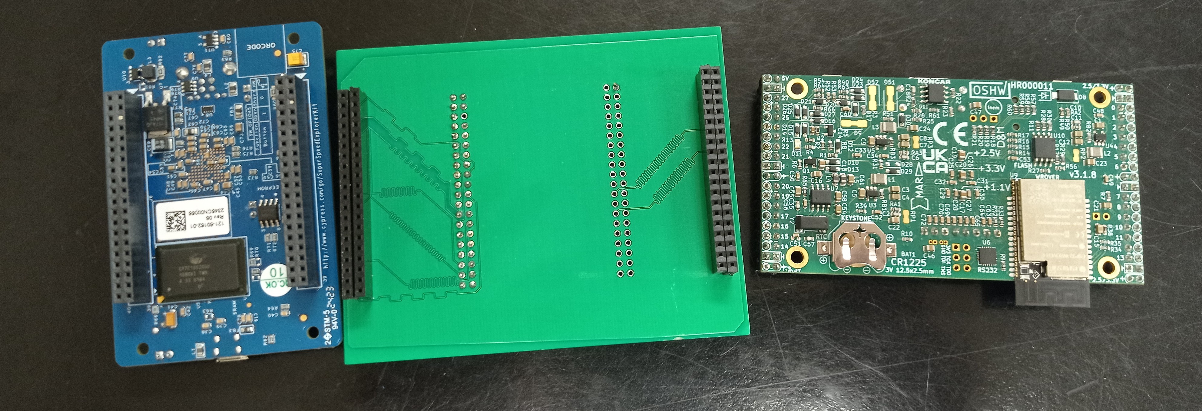
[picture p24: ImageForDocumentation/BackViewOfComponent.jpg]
Back view


# Installation Procedure
## 1. Connect the USB 3.0 wire
Connect the USB 3.0 Wire to the USB 3.0 Port on CyUSB3014 and connect the other end of the wire to USB 3.0 port on laptop. 

## 2. Connect the HDMI cable
Connect the HDMI cable to the HDMI port on ULX3s.
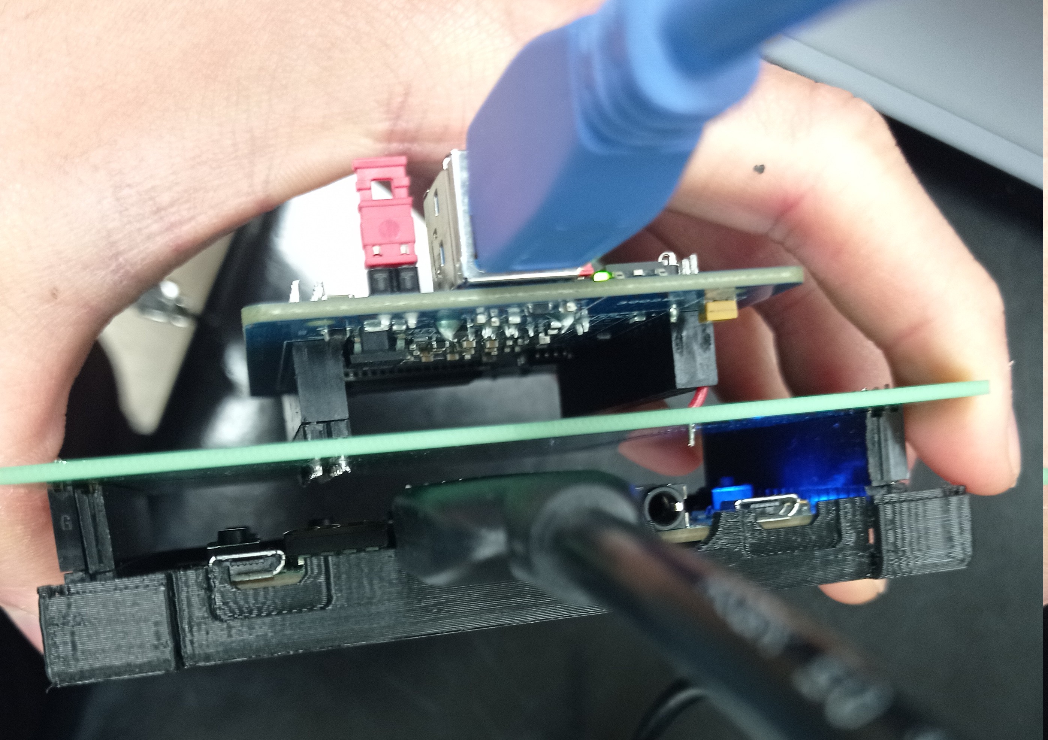
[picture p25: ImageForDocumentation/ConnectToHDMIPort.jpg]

## 3. (**Optional**: only require if never flashed the verilog code to ULX3s)

Connect the Micro USB 2.0 cable to the FPGA. Navigate to ***/ulx3s-misc-colonePath/examples/dvi*** (Refer to STEP 4 in __Prerequsite__ section of [TechnicalManual](./TechnicalMaunaul.md)), run the following command to flash the Verilog code to FPGA.
```bash
./loadToFlash.sh
```
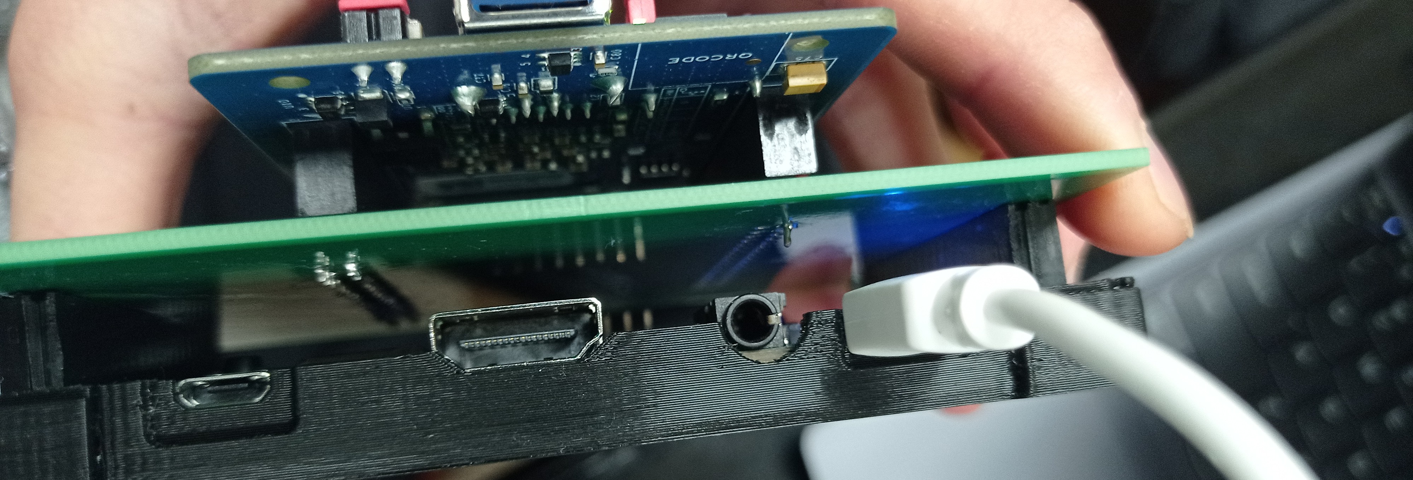
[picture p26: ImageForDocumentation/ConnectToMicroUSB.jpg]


# Instruction/Operation

### Step 1: Navigate to the modified Edid project
___cd___ to ___/pathOfClonedEdid/userProgram___ (refer to step 5 of **prerequisite** in [TechnicalManual](./TechnicalMaunaul.md)) 
### Step 2: Configure Screen Resolution in C++ code
Modify the [Line 199-2002](https://github.com/joeldushouyu/evdi/blob/userProgram/userProgram/main.cpp#L199-L202) in Main.cpp to select the EDID file that match to the desired screen information.

**NOTE**: To generate edid file for a screen resolution that is not included in the GitHub repo, please check out the [EDID](https://github.com/linuxhw/EDID) project by searching the [AnalogDisplay.md](https://github.com/linuxhw/EDID/blob/master/AnalogDisplay.md). Once located the did file, run the bash instruction under [How to install EDID file](https://github.com/linuxhw/EDID) and copy the new edid binary file to the project folder.

### Step 3: Build the C++ program
Run the following code to compile the program
```sh
make clean
make
```
### step 4 (Only when modified resolution setting in step 2 / Modified verilog code)
***cd*** to into the directory of ***/ulx3s-misc-colonePath/examples/dvi***  (refer to step 4 of __Prerequisite__ in [TechnicalManual](./TechnicalMaunaul.md) )

Modify [line 1-3](https://github.com/joeldushouyu/ulx3s-misc/blob/doubleFIFOImplementation/examples/dvi/top/top_usbtest.v#L1-L3) of top_usbtest.v

**NOTE** Due to the imperfect design of the PCB Conversion board, the current support resolution is listed below. For more details on the PCB conversion board, please refer to the [technical manual](./TechnicalMaunaul.md). **The list will be updated once a better PCB board design comes out**

|Resolution| FPS|
|--|--|
|640x400|30 or 60 HZ|
|640x480|30 or 60 HZ|
|720x576|30 HZ|
|800x480|30 HZ|
|1366x768|30 HZ|
|1280x1024|30 HZ|
|1920x1080|**25** HZ|

Re-compile the Verilog code and flash the Verilog by running the following command.
```bash
./loadToFlash.sh
```
### step 5 : Reset the FPGA state
Press the reset button for about __5 seconds__. 
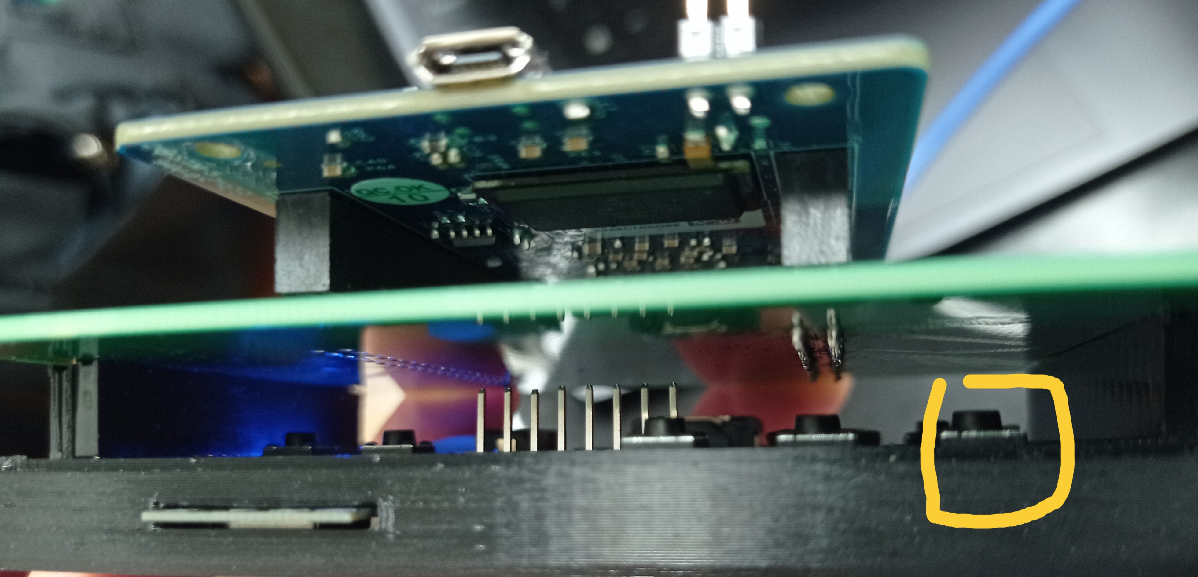
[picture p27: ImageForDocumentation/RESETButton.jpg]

**NOTE** Currently, the reset button is configured to be the right movement button(see Picture below). You are welcome to reconfigure the button by making change in the [verilog code](https://github.com/joeldushouyu/ulx3s-misc/blob/doubleFIFOImplementation/examples/dvi/top/top_usbtest.v#L88). However, be sure to remember to recompile and re-flash the verilog code after your change, refer to step 4 of **Instruction/Operation** .

### step 6 :  Launch the C++ program
___cd___ back to ___/pathOfClonedEdid/userProgram___ ( refer in step 1 of __Instruction/Operation__ ) and run the following command
```bash
./main
```

After __a few seconds__, the screen will blink and the monitor will show the newly configured screen.

# Troubleshooting
1. When the screen is distorted or out of the image
    1. First close the ./main program on the laptop by press ctrl+c
    2. Press the __reset__ button(refer to step 5 of __Instruction/Operation__) for around __5 seconds__ or longer. 
    3. Rerun the ./main program
2. When No image is showing on the monitor
    Refer to the __Instruction/Operation__ section to choose a lower/higher resolution screen setting. 

# Further Support / Assistant
If you have any issues or questions regarding the project, please create a new issue in the Github Repo and mention me in the discussion.  I will try my best to respond to the question as soon as possible.

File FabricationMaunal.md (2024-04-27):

# Fabrication Plan

## 1. Purchase ULX3s
Purchase a ULX3s board from [crowdsupply](https://www.crowdsupply.com/radiona/ulx3s#products), [Mouser](https://www.mouser.com/c/?q=ulx3s) or any available online supplier. **Any** version of ULX3s would work.
## 2. Purchase CyUSB3014 
Purchase a [CyUSB3014]((https://www.infineon.com/cms/en/product/evaluation-boards/cyusb3kit-003/)) device from the official website.
## 3. Purchase/Manufacture the PCB conversion board
Import the .sch and .brd file under [PCBboard](./PCBboard/CypressToULX3sVersion3/) into EagleCad or KiCad (KiCad support import project from EagleCad) and generate the Gerber file.  **NOTE**: The [Version3.zip](./PCBboard/CypressToULX3sVersion3/Version3.zip) is a existing Gerber file ready for printing with [JLCPCB](https://jlcpcb.com/).

## 4. Hardware Installation Procedure
####  Front View of Component
Front View
####  Back view of the Component
Back view

1. **Connect** the [Male header pins](https://www.amazon.com/dp/B0BX865TRT?ref=ppx_yo2ov_dt_b_product_details&th=1) onto the **Feale header pins** on CyUSB3014 Evaluation board and <code style="color:blue">Soldered the Male header pin </code> onto the PCB board, indicated by the <code style="color:blue"> Blue circle</code> in pictures above. 
2. **Solder** the [Male Header pins](https://www.amazon.com/dp/B09MYRVJ65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) onto I/O pins on ULX3s, indicated by the <code style="color:red"> Red Circles</code> in pictures above. The ULX3s do not come with soldered I/O pins.
3. **Connect** the [Female header pins](https://www.amazon.com/dp/B0BX865TRT?ref=ppx_yo2ov_dt_b_product_details&th=1) onto the  <code style="color:red">Soldered I/O pins on ULX3s</code> and **solder** the Female pin onto the PCB conversion board, indicated by the <code style="color:purple"> Purple Circles</code> in pictures above.

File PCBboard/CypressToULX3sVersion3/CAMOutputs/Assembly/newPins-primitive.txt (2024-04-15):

Partlist exported from /home/shouyu/EAGLE/projects/CypressToULX3sVersion3/newPins-primitive.sch at 4/13/24 1:28 PM

Qty Value     Device    Package   Parts               Description MF MPN OC_FARNELL OC_NEWARK POPULARITY
4   057-040-1 057-040-1 057-040-1 J1, J2, LEFT, RIGHT CONNECTOR          unknown    unknown   0

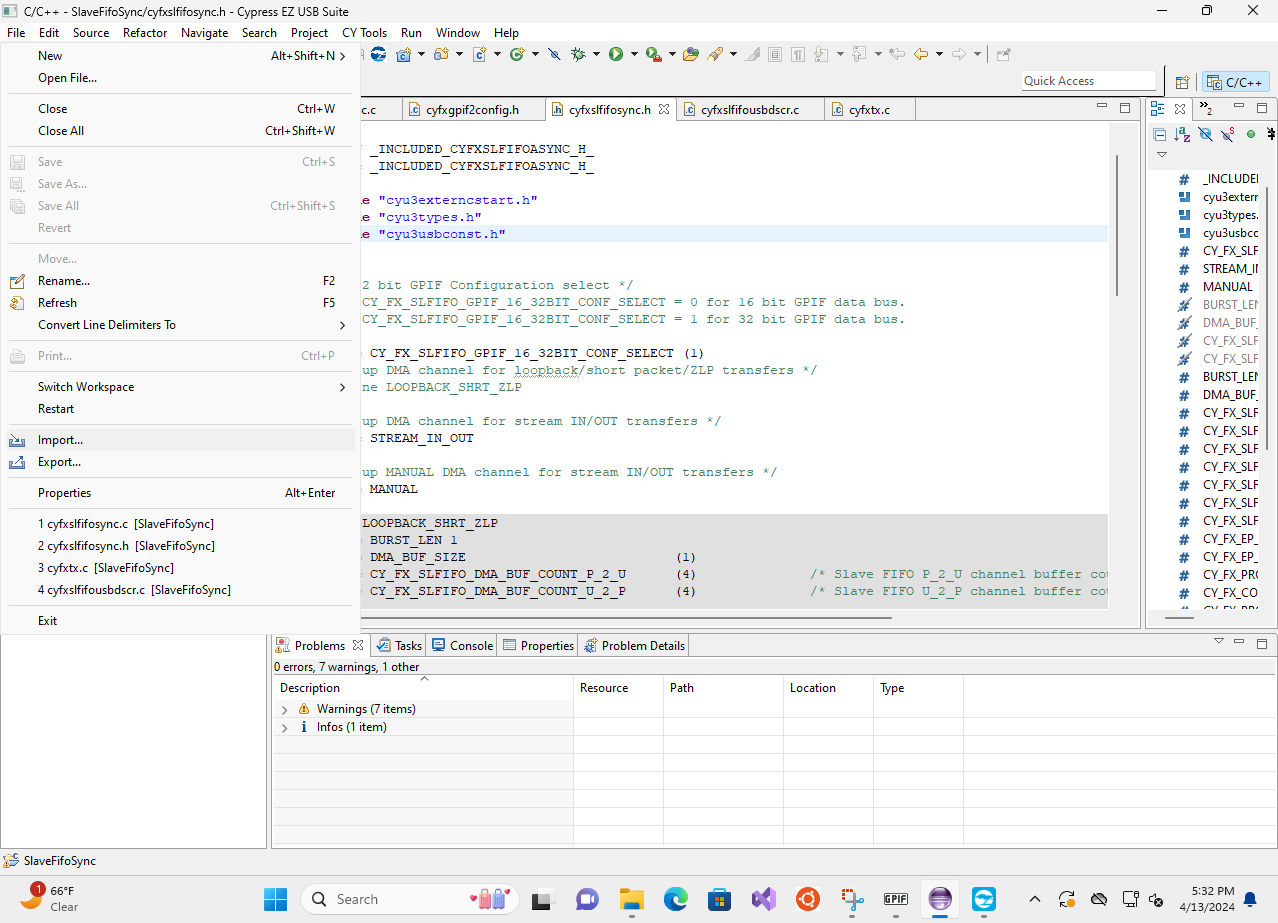
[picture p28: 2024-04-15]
ImageForDocumentation/StepForLoadingToCypressFx3/6.png

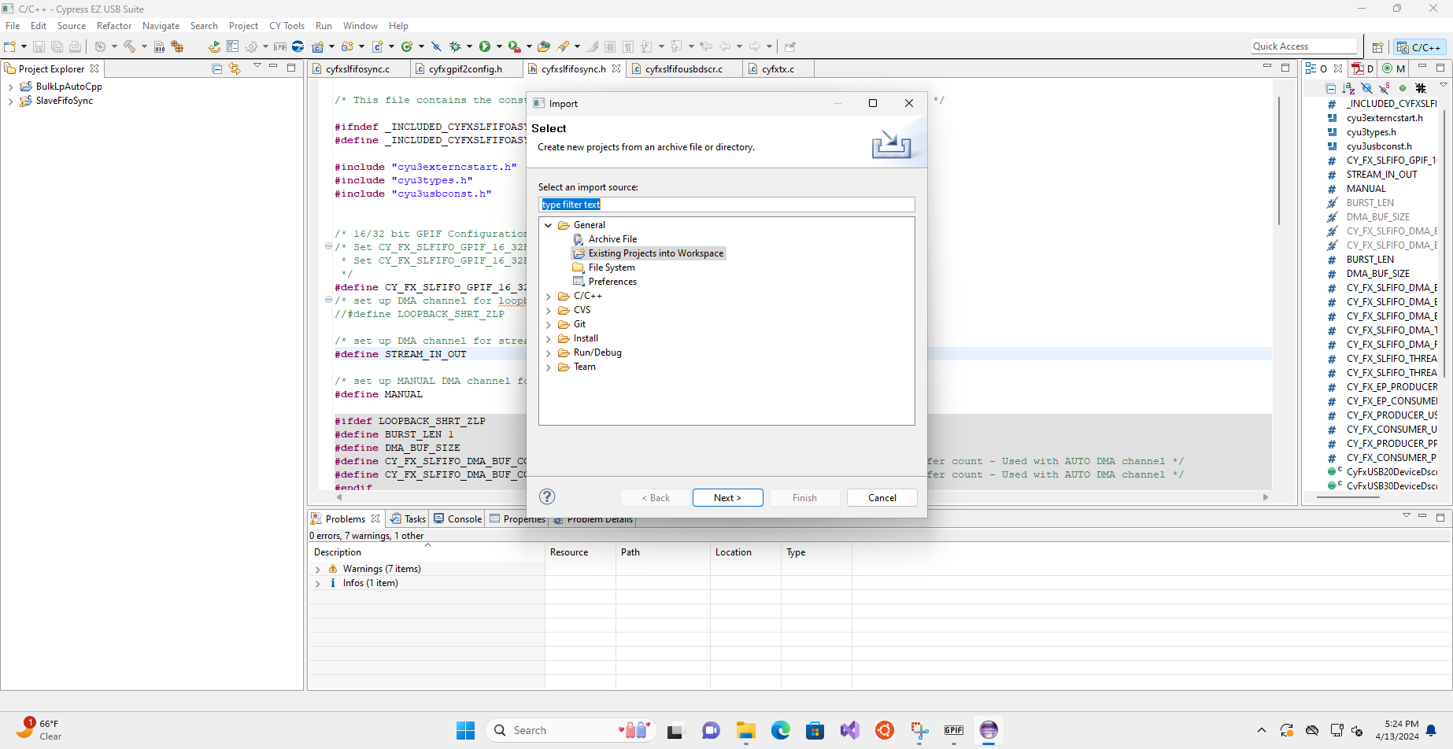
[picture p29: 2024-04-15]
ImageForDocumentation/StepForLoadingToCypressFx3/2.png

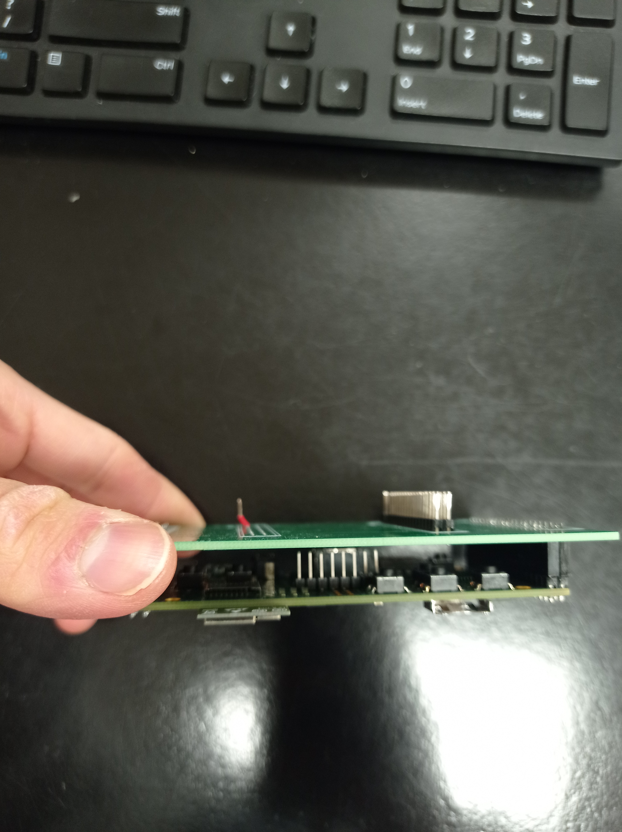
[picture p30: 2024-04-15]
ImageForDocumentation/SideViewOfHalfAssembledVersion2.jpg

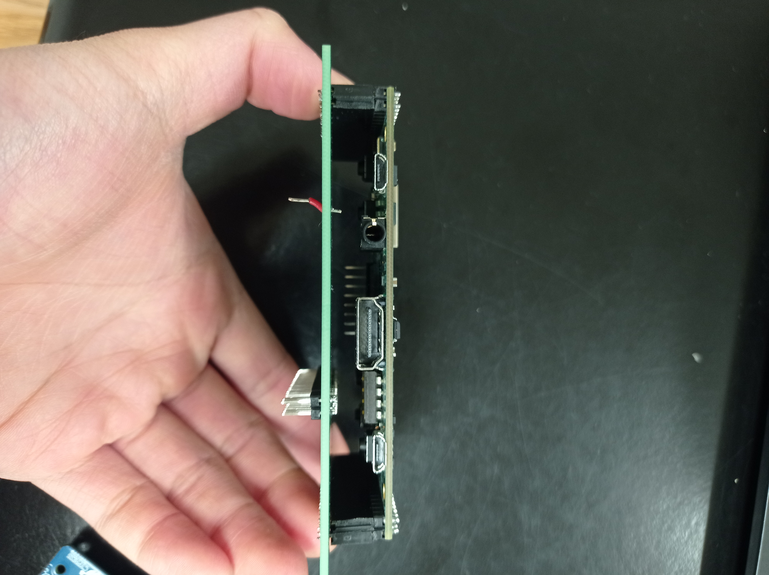
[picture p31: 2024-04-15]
ImageForDocumentation/SideViewOfHalfAssembled.jpg

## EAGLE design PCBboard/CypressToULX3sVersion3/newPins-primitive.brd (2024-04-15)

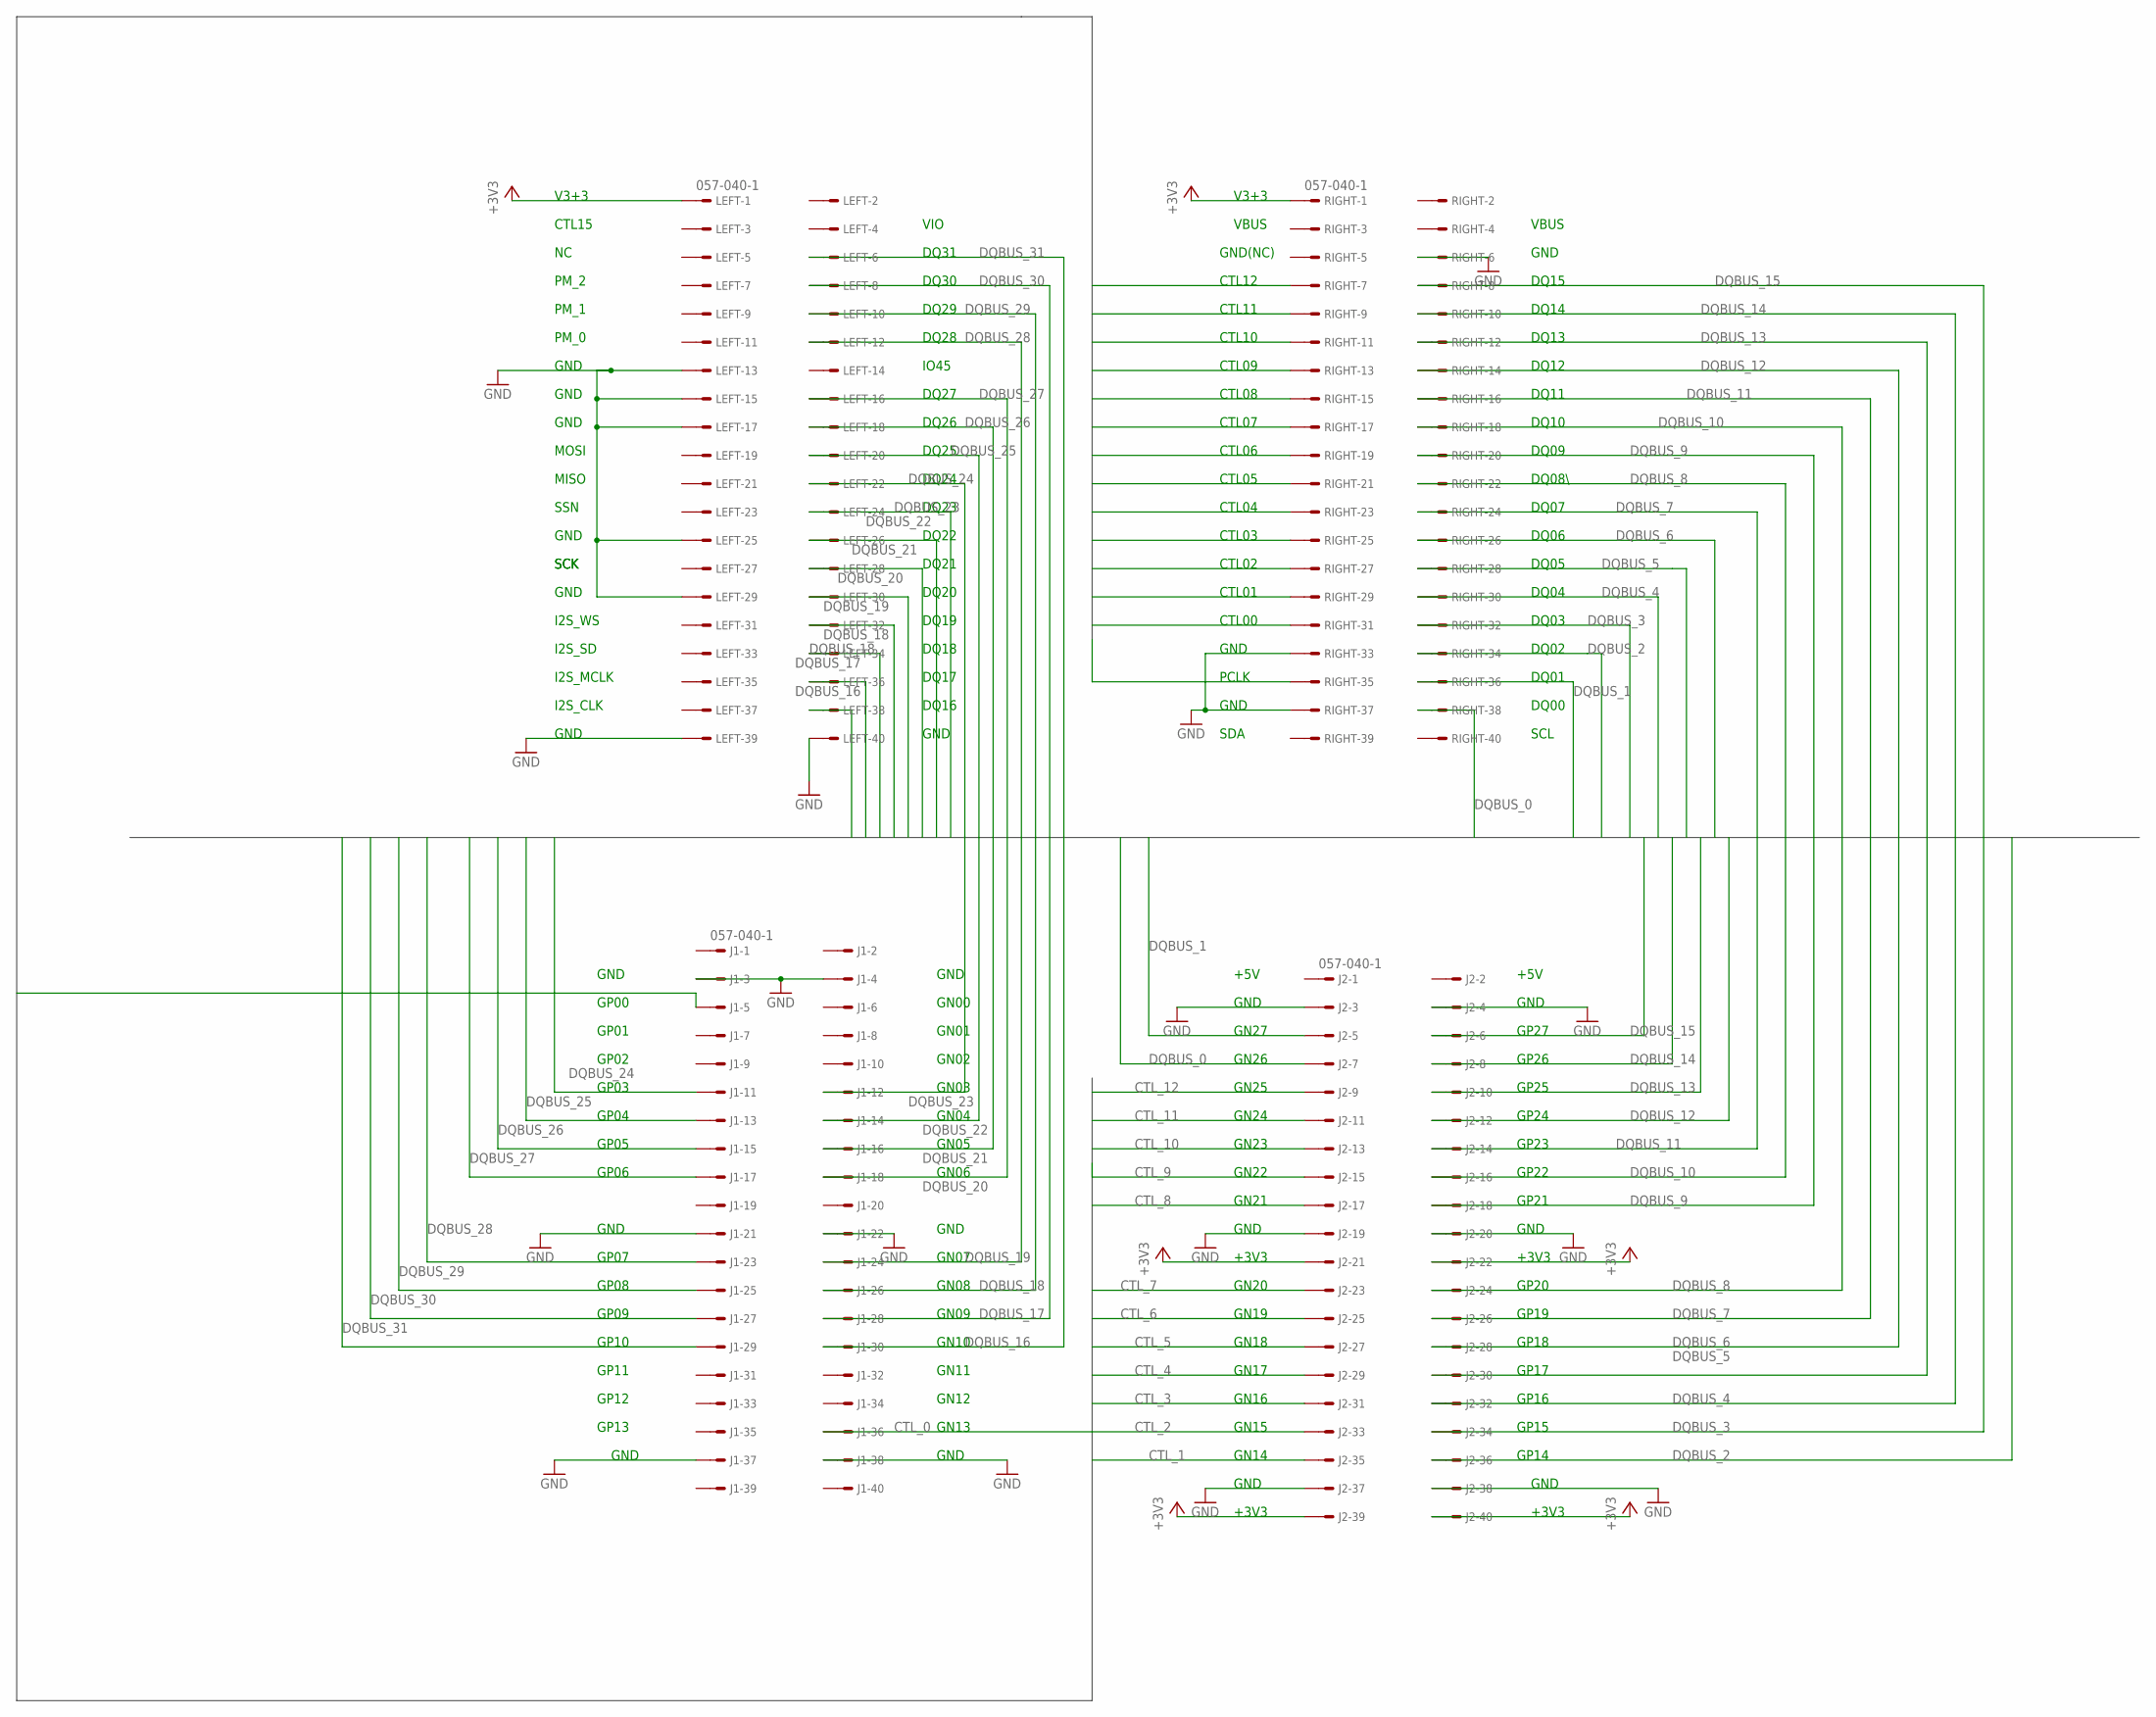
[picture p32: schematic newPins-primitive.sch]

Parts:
J1, J2: 057-040-1
LEFT: 057-040-1
RIGHT: 057-040-1

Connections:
+3V3: J2.21, J2.22, J2.39, J2.40, LEFT.1, RIGHT.1
CTL_0: J1.36, RIGHT.31
CTL_1: J2.35, RIGHT.29
CTL_2: J2.33, RIGHT.27
CTL_3: J2.31, RIGHT.25
CTL_4: J2.29, RIGHT.23
CTL_5: J2.27, RIGHT.21
CTL_6: J2.25, RIGHT.19
CTL_7: J2.23, RIGHT.17
CTL_8: J2.17, RIGHT.15
CTL_9: J2.15, RIGHT.13
CTL_10: J2.13, RIGHT.11
CTL_11: J2.11, RIGHT.9
CTL_12: J2.9, RIGHT.7
CTL_PCLK: J1.5, RIGHT.35
DQBUS_0: J2.7, RIGHT.38
DQBUS_1: J2.5, RIGHT.36
DQBUS_2: J2.36, RIGHT.34
DQBUS_3: J2.34, RIGHT.32
DQBUS_4: J2.32, RIGHT.30
DQBUS_5: J2.30, RIGHT.28
DQBUS_6: J2.28, RIGHT.26
DQBUS_7: J2.26, RIGHT.24
DQBUS_8: J2.24, RIGHT.22
DQBUS_9: J2.18, RIGHT.20
DQBUS_10: J2.16, RIGHT.18
DQBUS_11: J2.14, RIGHT.16
DQBUS_12: J2.12, RIGHT.14
DQBUS_13: J2.10, RIGHT.12
DQBUS_14: J2.8, RIGHT.10
DQBUS_15: J2.6, RIGHT.8
DQBUS_16: J1.30, LEFT.38
DQBUS_17: J1.28, LEFT.36
DQBUS_18: J1.26, LEFT.34
DQBUS_19: J1.24, LEFT.32
DQBUS_20: J1.18, LEFT.30
DQBUS_21: J1.16, LEFT.28
DQBUS_22: J1.14, LEFT.26
DQBUS_23: J1.12, LEFT.24
DQBUS_24: J1.11, LEFT.22
DQBUS_25: J1.13, LEFT.20
DQBUS_26: J1.15, LEFT.18
DQBUS_27: J1.17, LEFT.16
DQBUS_28: J1.23, LEFT.12
DQBUS_29: J1.25, LEFT.10
DQBUS_30: J1.27, LEFT.8
DQBUS_31: J1.29, LEFT.6
GND: J1.3, J1.4, J1.21, J1.22, J1.37, J1.38, J2.3, J2.4, J2.19, J2.20, J2.37, J2.38, LEFT.13, LEFT.15, LEFT.17, LEFT.25, LEFT.29, LEFT.39, LEFT.40, RIGHT.6, RIGHT.33, RIGHT.37

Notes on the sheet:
+5V
GND
+3V3
GP27
GP26
GP25
GP24
GP23
GP22
GP21
GP20
GP19
GP18
GP17
GP16
GP15
GP14
GN14
GN15
GN16
GN17
GN18
GN19
GN20
GN21
GN22
GN23
GN24
GN25
GN26
GN27
GN13
GN12
GN11
GN10
GN09
GN08
GN07
GN06
GN05

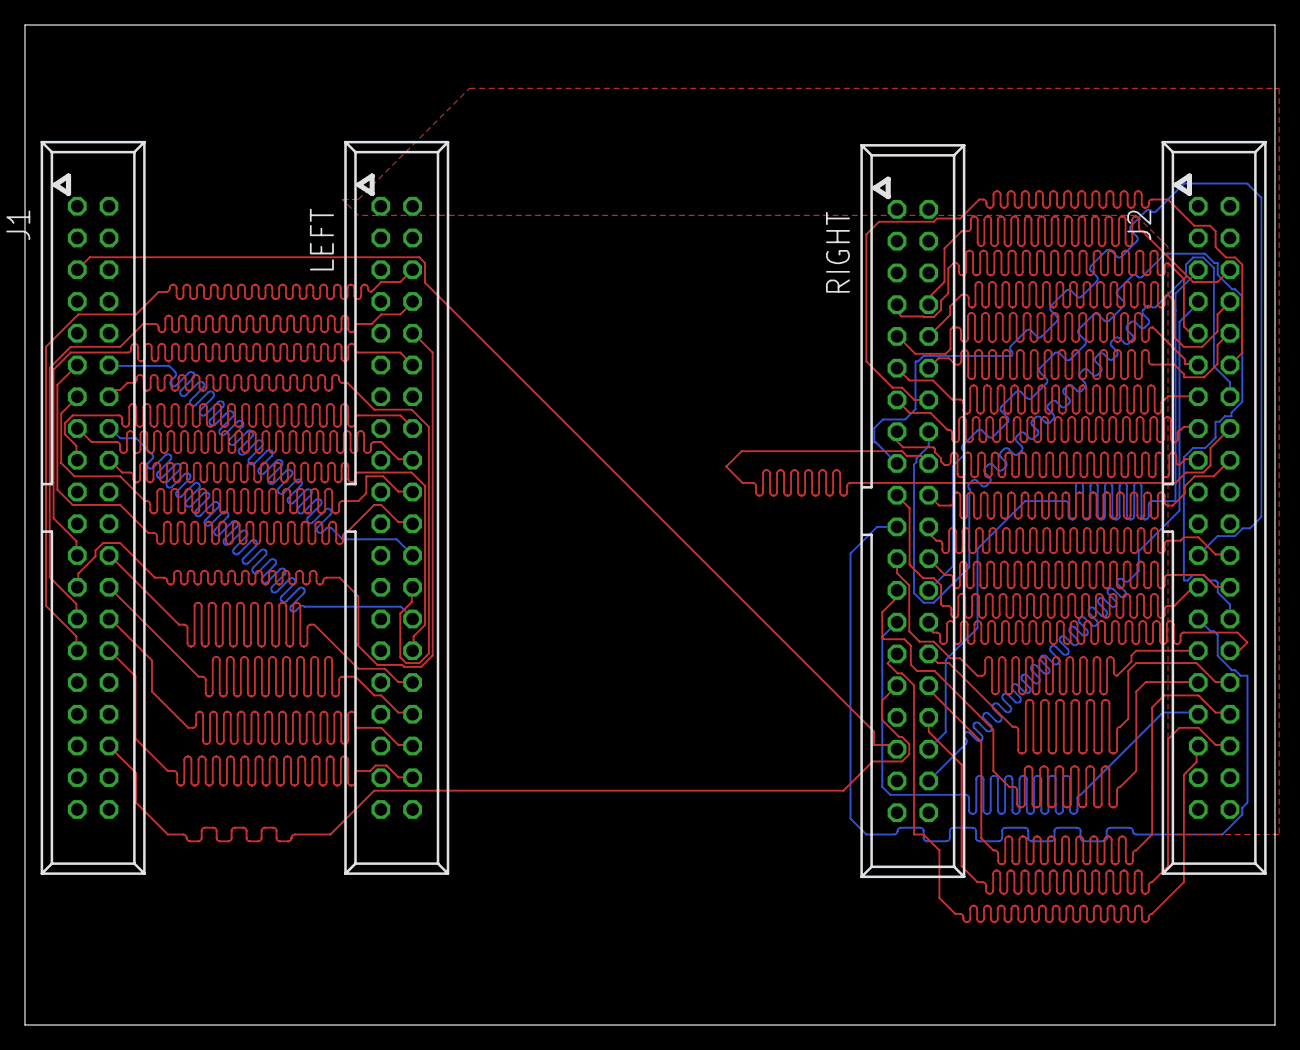
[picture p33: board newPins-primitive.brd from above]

Board: 2 copper layers, 100.0 x 80.0 mm, 4 parts (0 on the bottom side), 48 nets.

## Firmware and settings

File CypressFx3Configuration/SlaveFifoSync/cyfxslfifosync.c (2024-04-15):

/*
 ## Cypress USB 3.0 Platform source file (cyfxslfifosync.c)
 ## ===========================
 ##
 ##  Copyright Cypress Semiconductor Corporation, 2010-2011,
 ##  All Rights Reserved
 ##  UNPUBLISHED, LICENSED SOFTWARE.
 ##
 ##  CONFIDENTIAL AND PROPRIETARY INFORMATION
 ##  WHICH IS THE PROPERTY OF CYPRESS.
 ##
 ##  Use of this file is governed
 ##  by the license agreement included in the file
 ##
 ##     <install>/license/license.txt
 ##
 ##  where <install> is the Cypress software
 ##  installation root directory path.
 ##
 ## ===========================
*/

/* This file illustrates the Slave FIFO Synchronous mode example */

/*
   This example comprises of two USB bulk endpoints. A bulk OUT endpoint acts as the
   producer of data from the host. A bulk IN endpoint acts as the consumer of data to
   the host. Appropriate vendor class USB enumeration descriptors with these two bulk
   endpoints are implemented.

   The GPIF configuration data for the Synchronous Slave FIFO operation is loaded onto
   the appropriate GPIF registers. The p-port data transfers are done via the producer
   p-port socket and the consumer p-port socket.

   This example implements two DMA Channels either in MANUAL mode or AUTO mode (depending
   on #define MANUAL in cyfxslfifosync.h) one for P to U data transfer and one for U to P
   data transfer.

   The U to P DMA channel connects the USB producer (OUT) endpoint to the consumer p-port
   socket. And the P to U DMA channel connects the producer p-port socket to the USB 
   consumer (IN) endpoint.

   In case of MANUAL DMA channel, Upon every reception of data in the DMA buffer from the
   host or from the p-port, the CPU is signaled using DMA callbacks. There are two DMA callback
   functions implemented each for U to P and P to U data paths. The CPU then commits the DMA buffer received so
   that the data is transferred to the consumer.

   In case of AUTO DMA channel, the data will be transferred between U and P ports automatically
   without any intervention from the CPU.

   The DMA buffer size is configured differently based on the usage. #define LOOPBACK_SHRT_ZLP in cyfxslfifosync.h
   configures the DMA buffers for doing data loopback. Also, DMA buffer for each channel is defined based on the
   USB speed. 64 bytes for full speed, 512 bytes for high speed and 1024 bytes for super speed.
   #define STREAM_IN_OUT in cyfxslfifosync.h configures the DMA buffers for higher bandwidth data transfers.
   16*64 bytes for full speed, 16*512 bytes for high speed and 16*1024 bytes for super speed.

   CY_FX_SLFIFO_DMA_BUF_COUNT_P_2_U in cyfxslfifosync.h defines the number of DMA buffers allocated for P to U data path.
   CY_FX_SLFIFO_DMA_BUF_COUNT_U_2_P in cyfxslfifosync.h defines the number of DMA buffers allocated for U to P data path.

   The constant CY_FX_SLFIFO_GPIF_16_32BIT_CONF_SELECT in the header file is used to
   select 16bit or 32bit GPIF data bus configuration.
 */

#include "cyu3system.h"
#include "cyu3os.h"
#include "cyu3dma.h"
#include "cyu3error.h"
#include "cyu3usb.h"
#include "cyu3uart.h"
#include "cyfxslfifosync.h"
#include "cyu3gpif.h"
#include "cyu3pib.h"
#include "pib_regs.h"
#include <cyu3gpio.h>

/* This file should be included only once as it contains
 * structure definitions. Including it in multiple places
 * can result in linker error. */

#include "cyfxgpif2config.h"


CyU3PThread slFifoAppThread;	        /* Slave FIFO application thread structure */
CyU3PDmaChannel glChHandleSlFifoUtoP;   /* DMA Channel handle for U2P transfer. */
CyU3PDmaChannel glChHandleSlFifoPtoU;   /* DMA Channel handle for P2U transfer. */

uint32_t glDMARxCount = 0;               /* Counter to track the number of buffers received from USB. */
uint32_t glDMATxCount = 0;               /* Counter to track the number of buffers sent to USB. */
CyBool_t glIsApplnActive = CyFalse;      /* Whether the loopback application is active or not. */
uint8_t burstLength = 0;
/* Application Error Handler */
void
CyFxAppErrorHandler (
        CyU3PReturnStatus_t apiRetStatus    /* API return status */
        )
{
    /* Application failed with the error code apiRetStatus */

    /* Add custom debug or recovery actions here */

    /* Loop Indefinitely */
    for (;;)
    {
        /* Thread sleep : 100 ms */
        CyU3PThreadSleep (100);
    }
}

/* This function initializes the debug module. The debug prints
 * are routed to the UART and can be seen using a UART console
 * running at 115200 baud rate. */
void
CyFxSlFifoApplnDebugInit (void)
{
    CyU3PUartConfig_t uartConfig;
    CyU3PReturnStatus_t apiRetStatus = CY_U3P_SUCCESS;
    /* Initialize the UART for printing debug messages */
    apiRetStatus = CyU3PUartInit();
    if (apiRetStatus != CY_U3P_SUCCESS)
    {
        /* Error handling */
        CyFxAppErrorHandler(apiRetStatus);
    }

    /* Set UART configuration */
    CyU3PMemSet ((uint8_t *)&uartConfig, 0, sizeof (uartConfig));
    uartConfig.baudRate = CY_U3P_UART_BAUDRATE_115200;
    uartConfig.stopBit = CY_U3P_UART_ONE_STOP_BIT;
    uartConfig.parity = CY_U3P_UART_NO_PARITY;
    uartConfig.txEnable = CyTrue;
    uartConfig.rxEnable = CyFalse;
    uartConfig.flowCtrl = CyFalse;
    uartConfig.isDma = CyTrue;

    apiRetStatus = CyU3PUartSetConfig (&uartConfig, NULL);
    if (apiRetStatus != CY_U3P_SUCCESS)
    {
        CyFxAppErrorHandler(apiRetStatus);
    }

    /* Set the UART transfer to a really large value. */
    apiRetStatus = CyU3PUartTxSetBlockXfer (0xFFFFFFFF);
    if (apiRetStatus != CY_U3P_SUCCESS)
    {
        CyFxAppErrorHandler(apiRetStatus);
    }

    /* Initialize the debug module. */
    apiRetStatus = CyU3PDebugInit (CY_U3P_LPP_SOCKET_UART_CONS, 8);
    if (apiRetStatus != CY_U3P_SUCCESS)
    {
        CyFxAppErrorHandler(apiRetStatus);
    }
}

/* DMA callback function to handle the produce events for U to P transfers. */
void
CyFxSlFifoUtoPDmaCallback (
        CyU3PDmaChannel   *chHandle,
        CyU3PDmaCbType_t  type,
        CyU3PDmaCBInput_t *input
        )
{
    CyU3PReturnStatus_t status = CY_U3P_SUCCESS;

    if (type == CY_U3P_DMA_CB_PROD_EVENT)
    {
        /* This is a produce event notification to the CPU. This notification is 
         * received upon reception of every buffer. The buffer will not be sent
         * out unless it is explicitly committed. The call shall fail if there
         * is a bus reset / usb disconnect or if there is any application error. */
        status = CyU3PDmaChannelCommitBuffer (chHandle, input->buffer_p.count, 0);
        if (status != CY_U3P_SUCCESS)
        {
            CyU3PDebugPrint (4, "CyU3PDmaChannelCommitBuffer failed, Error code = %d\n", status);
        }

        /* Increment the counter. */
        glDMARxCount++;
    }
}

/* DMA callback function to handle the produce events for P to U transfers. */
void
CyFxSlFifoPtoUDmaCallback (
        CyU3PDmaChannel   *chHandle,
        CyU3PDmaCbType_t  type,
        CyU3PDmaCBInput_t *input
        )
{
    CyU3PReturnStatus_t status = CY_U3P_SUCCESS;

    if (type == CY_U3P_DMA_CB_PROD_EVENT)
    {
        /* This is a produce event notification to the CPU. This notification is 
         * received upon reception of every buffer. The buffer will not be sent
         * out unless it is explicitly committed. The call shall fail if there
         * is a bus reset / usb disconnect or if there is any application error. */
        status = CyU3PDmaChannelCommitBuffer (chHandle, input->buffer_p.count, 0);
        if (status != CY_U3P_SUCCESS)
        {
            CyU3PDebugPrint (4, "CyU3PDmaChannelCommitBuffer failed, Error code = %d\n", status);
        }

        /* Increment the counter. */
        glDMATxCount++;
    }
}

/* This function starts the slave FIFO loop application. This is called
 * when a SET_CONF event is received from the USB host. The endpoints
 * are configured and the DMA pipe is setup in this function. */
void
CyFxSlFifoApplnStart (
        void)
{
    uint16_t size = 0;
    CyU3PEpConfig_t epCfg;
    CyU3PDmaChannelConfig_t dmaCfg;
    CyU3PReturnStatus_t apiRetStatus = CY_U3P_SUCCESS;
    CyU3PUSBSpeed_t usbSpeed = CyU3PUsbGetSpeed();

    /* First identify the usb speed. Once that is identified,
     * create a DMA channel and start the transfer on this. */

    /* Based on the Bus Speed configure the endpoint packet size */
    switch (usbSpeed)
    {
        case CY_U3P_FULL_SPEED:
            size = 64;
            break;

        case CY_U3P_HIGH_SPEED:
            size = 512;
            burstLength=1;

            break;

        case  CY_U3P_SUPER_SPEED:
            size = 1024;
            burstLength=16;
            break;

        default:
            CyU3PDebugPrint (4, "Error! Invalid USB speed.\n");
            CyFxAppErrorHandler (CY_U3P_ERROR_FAILURE);
            break;
    }

    CyU3PMemSet ((uint8_t *)&epCfg, 0, sizeof (epCfg));
    epCfg.enable = CyTrue;
    epCfg.epType = CY_U3P_USB_EP_BULK;
#ifdef STREAM_IN_OUT
    epCfg.burstLen = burstLength;
#else
    epCfg.burstLen = 1;
#endif
    epCfg.streams = 0;
    epCfg.pcktSize = size;

    /* Producer endpoint configuration */

    apiRetStatus = CyU3PSetEpConfig(CY_FX_EP_PRODUCER, &epCfg);
    if (apiRetStatus != CY_U3P_SUCCESS)
    {
        CyU3PDebugPrint (4, "CyU3PSetEpConfig failed, Error code = %d\n", apiRetStatus);
        CyFxAppErrorHandler (apiRetStatus);
    }

    /* Consumer endpoint configuration */

    apiRetStatus = CyU3PSetEpConfig(CY_FX_EP_CONSUMER, &epCfg);
    if (apiRetStatus != CY_U3P_SUCCESS)
    {
        CyU3PDebugPrint (4, "CyU3PSetEpConfig failed, Error code = %d\n", apiRetStatus);
        CyFxAppErrorHandler (apiRetStatus);
    }

#ifdef MANUAL
    /* Create a DMA MANUAL channel for U2P transfer.
     * DMA size is set based on the USB speed. */
    dmaCfg.size  = DMA_BUF_SIZE* size;
    dmaCfg.count = CY_FX_SLFIFO_DMA_BUF_COUNT_U_2_P;
    dmaCfg.prodSckId = CY_FX_PRODUCER_USB_SOCKET;
    dmaCfg.consSckId = CY_FX_CONSUMER_PPORT_SOCKET;
    dmaCfg.dmaMode = CY_U3P_DMA_MODE_BYTE;
    /* Enabling the callback for produce event. */
    dmaCfg.notification = CY_U3P_DMA_CB_PROD_EVENT;
    dmaCfg.cb = CyFxSlFifoUtoPDmaCallback;
    dmaCfg.prodHeader = 0;
    dmaCfg.prodFooter = 0;
    dmaCfg.consHeader = 0;
    dmaCfg.prodAvailCount = 0;

    apiRetStatus = CyU3PDmaChannelCreate (&glChHandleSlFifoUtoP,
            CY_U3P_DMA_TYPE_MANUAL, &dmaCfg);
    if (apiRetStatus != CY_U3P_SUCCESS)
    {
        CyU3PDebugPrint (4, "CyU3PDmaChannelCreate failed, Error code = %d\n", apiRetStatus);
        CyFxAppErrorHandler(apiRetStatus);
    }

    /* Create a DMA MANUAL channel for P2U transfer. */
    dmaCfg.prodSckId = CY_FX_PRODUCER_PPORT_SOCKET;
    dmaCfg.consSckId = CY_FX_CONSUMER_USB_SOCKET;
    dmaCfg.count = CY_FX_SLFIFO_DMA_BUF_COUNT_P_2_U;
    dmaCfg.cb = CyFxSlFifoPtoUDmaCallback;

    apiRetStatus = CyU3PDmaChannelCreate (&glChHandleSlFifoPtoU,
            CY_U3P_DMA_TYPE_MANUAL, &dmaCfg);

#else
    /* Create a DMA AUTO channel for U2P transfer.
       DMA size is set based on the USB speed. */
    dmaCfg.size  = DMA_BUF_SIZE* size;
    dmaCfg.count = CY_FX_SLFIFO_DMA_BUF_COUNT_U_2_P;
	dmaCfg.prodSckId = CY_FX_PRODUCER_USB_SOCKET;
    dmaCfg.consSckId = CY_FX_CONSUMER_PPORT_SOCKET;
    dmaCfg.dmaMode = CY_U3P_DMA_MODE_BYTE;
    /* Enabling the callback for produce event. */
    dmaCfg.notification = 0;
    dmaCfg.cb = NULL;
    dmaCfg.prodHeader = 0;
    dmaCfg.prodFooter = 0;
    dmaCfg.consHeader = 0;
    dmaCfg.prodAvailCount = 0;

    apiRetStatus = CyU3PDmaChannelCreate (&glChHandleSlFifoUtoP,
               CY_U3P_DMA_TYPE_AUTO, &dmaCfg);
    if (apiRetStatus != CY_U3P_SUCCESS)
    {
       CyU3PDebugPrint (4, "CyU3PDmaChannelCreate failed, Error code = %d\n", apiRetStatus);
       CyFxAppErrorHandler(apiRetStatus);
    }

    /* Create a DMA AUTO channel for P2U transfer. */
    dmaCfg.size  = DMA_BUF_SIZE*size; //increase buffer size for higher performance
    dmaCfg.count = CY_FX_SLFIFO_DMA_BUF_COUNT_P_2_U; // increase buffer count for higher performance
    dmaCfg.prodSckId = CY_FX_PRODUCER_PPORT_SOCKET;
    dmaCfg.consSckId = CY_FX_CONSUMER_USB_SOCKET;
    dmaCfg.cb = NULL;
    apiRetStatus = CyU3PDmaChannelCreate (&glChHandleSlFifoPtoU,
               CY_U3P_DMA_TYPE_AUTO, &dmaCfg);

    if (apiRetStatus != CY_U3P_SUCCESS)
    {
        CyU3PDebugPrint (4, "CyU3PDmaChannelCreate failed, Error code = %d\n", apiRetStatus);
        CyFxAppErrorHandler(apiRetStatus);
    }

#endif

    /* Flush the Endpoint memory */
    CyU3PUsbFlushEp(CY_FX_EP_PRODUCER);
    CyU3PUsbFlushEp(CY_FX_EP_CONSUMER);

    /* Set DMA channel transfer size. */
    apiRetStatus = CyU3PDmaChannelSetXfer (&glChHandleSlFifoUtoP, CY_FX_SLFIFO_DMA_TX_SIZE);
    if (apiRetStatus != CY_U3P_SUCCESS)
    {
        CyU3PDebugPrint (4, "CyU3PDmaChannelSetXfer Failed, Error code = %d\n", apiRetStatus);
        CyFxAppErrorHandler(apiRetStatus);
    }
    apiRetStatus = CyU3PDmaChannelSetXfer (&glChHandleSlFifoPtoU, CY_FX_SLFIFO_DMA_RX_SIZE);
    if (apiRetStatus != CY_U3P_SUCCESS)
    {
        CyU3PDebugPrint (4, "CyU3PDmaChannelSetXfer Failed, Error code = %d\n", apiRetStatus);
        CyFxAppErrorHandler(apiRetStatus);
    }

    /* Update the status flag. */
    glIsApplnActive = CyTrue;
    CyU3PGpioSetValue (59, CyFalse);
}

/* This function stops the slave FIFO loop application. This shall be called
 * whenever a RESET or DISCONNECT event is received from the USB host. The
 * endpoints are disabled and the DMA pipe is destroyed by this function. */
void
CyFxSlFifoApplnStop (
        void)
{
    CyU3PEpConfig_t epCfg;
    CyU3PReturnStatus_t apiRetStatus = CY_U3P_SUCCESS;

    /* Update the flag. */
    glIsApplnActive = CyFalse;

    /* Flush the endpoint memory */
    CyU3PUsbFlushEp(CY_FX_EP_PRODUCER);
    CyU3PUsbFlushEp(CY_FX_EP_CONSUMER);

    /* Destroy the channel */
    CyU3PDmaChannelDestroy (&glChHandleSlFifoUtoP);
    CyU3PDmaChannelDestroy (&glChHandleSlFifoPtoU);

    /* Disable endpoints. */
    CyU3PMemSet ((uint8_t *)&epCfg, 0, sizeof (epCfg));
    epCfg.enable = CyFalse;

    /* Producer endpoint configuration. */
    apiRetStatus = CyU3PSetEpConfig(CY_FX_EP_PRODUCER, &epCfg);
    if (apiRetStatus != CY_U3P_SUCCESS)
    {
        CyU3PDebugPrint (4, "CyU3PSetEpConfig failed, Error code = %d\n", apiRetStatus);
        CyFxAppErrorHandler (apiRetStatus);
    }

    /* Consumer endpoint configuration. */
    apiRetStatus = CyU3PSetEpConfig(CY_FX_EP_CONSUMER, &epCfg);
    if (apiRetStatus != CY_U3P_SUCCESS)
    {
        CyU3PDebugPrint (4, "CyU3PSetEpConfig failed, Error code = %d\n", apiRetStatus);
        CyFxAppErrorHandler (apiRetStatus);
    }
}

/* Callback to handle the USB setup requests. */
CyBool_t
CyFxSlFifoApplnUSBSetupCB (
        uint32_t setupdat0,
        uint32_t setupdat1
    )
{
    /* Fast enumeration is used. Only requests addressed to the interface, class,
     * vendor and unknown control requests are received by this function.
     * This application does not support any class or vendor requests. */

    uint8_t  bRequest, bReqType;
    uint8_t  bType, bTarget;
    uint16_t wValue, wIndex;
    CyBool_t isHandled = CyFalse;

    /* Decode the fields from the setup request. */
    bReqType = (setupdat0 & CY_U3P_USB_REQUEST_TYPE_MASK);
    bType    = (bReqType & CY_U3P_USB_TYPE_MASK);
    bTarget  = (bReqType & CY_U3P_USB_TARGET_MASK);
    bRequest = ((setupdat0 & CY_U3P_USB_REQUEST_MASK) >> CY_U3P_USB_REQUEST_POS);
    wValue   = ((setupdat0 & CY_U3P_USB_VALUE_MASK)   >> CY_U3P_USB_VALUE_POS);
    wIndex   = ((setupdat1 & CY_U3P_USB_INDEX_MASK)   >> CY_U3P_USB_INDEX_POS);

    if (bType == CY_U3P_USB_STANDARD_RQT)
    {
        /* Handle SET_FEATURE(FUNCTION_SUSPEND) and CLEAR_FEATURE(FUNCTION_SUSPEND)
         * requests here. It should be allowed to pass if the device is in configured
         * state and failed otherwise. */
        if ((bTarget == CY_U3P_USB_TARGET_INTF) && ((bRequest == CY_U3P_USB_SC_SET_FEATURE)
                    || (bRequest == CY_U3P_USB_SC_CLEAR_FEATURE)) && (wValue == 0))
        {
            if (glIsApplnActive)
                CyU3PUsbAckSetup ();
            else
                CyU3PUsbStall (0, CyTrue, CyFalse);

            isHandled = CyTrue;
        }

        /* CLEAR_FEATURE request for endpoint is always passed to the setup callback
         * regardless of the enumeration model used. When a clear feature is received,
         * the previous transfer has to be flushed and cleaned up. This is done at the
         * protocol level. Since this is just a loopback operation, there is no higher
         * level protocol. So flush the EP memory and reset the DMA channel associated
         * with it. If there are more than one EP associated with the channel reset both
         * the EPs. The endpoint stall and toggle / sequence number is also expected to be
         * reset. Return CyFalse to make the library clear the stall and reset the endpoint
         * toggle. Or invoke the CyU3PUsbStall (ep, CyFalse, CyTrue) and return CyTrue.
         * Here we are clearing the stall. */
        if ((bTarget == CY_U3P_USB_TARGET_ENDPT) && (bRequest == CY_U3P_USB_SC_CLEAR_FEATURE)
                && (wValue == CY_U3P_USBX_FS_EP_HALT))
        {
            if (glIsApplnActive)
            {
                if (wIndex == CY_FX_EP_PRODUCER)
                {
                    CyU3PDmaChannelReset (&glChHandleSlFifoUtoP);
                    CyU3PUsbFlushEp(CY_FX_EP_PRODUCER);
                    CyU3PUsbResetEp (CY_FX_EP_PRODUCER);
                    CyU3PDmaChannelSetXfer (&glChHandleSlFifoUtoP, CY_FX_SLFIFO_DMA_TX_SIZE);
                }

                if (wIndex == CY_FX_EP_CONSUMER)
                {
                    CyU3PDmaChannelReset (&glChHandleSlFifoPtoU);
                    CyU3PUsbFlushEp(CY_FX_EP_CONSUMER);
                    CyU3PUsbResetEp (CY_FX_EP_CONSUMER);
                    CyU3PDmaChannelSetXfer (&glChHandleSlFifoPtoU, CY_FX_SLFIFO_DMA_RX_SIZE);
                }

                CyU3PUsbStall (wIndex, CyFalse, CyTrue);
                isHandled = CyTrue;
            }
        }
    }

    return isHandled;
}

/* This is the callback function to handle the USB events. */
void
CyFxSlFifoApplnUSBEventCB (
    CyU3PUsbEventType_t evtype,
    uint16_t            evdata
    )
{
    switch (evtype)
    {
        case CY_U3P_USB_EVENT_SETCONF:
            /* Stop the application before re-starting. */
            if (glIsApplnActive)
            {
                CyFxSlFifoApplnStop ();
            }
            CyU3PUsbLPMDisable();
            /* Start the loop back function. */
            CyFxSlFifoApplnStart ();
            break;

        case CY_U3P_USB_EVENT_RESET:
        case CY_U3P_USB_EVENT_DISCONNECT:
            /* Stop the loop back function. */
            if (glIsApplnActive)
            {
                CyFxSlFifoApplnStop ();
            }
            break;

        default:
            break;
    }
}
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
int
main (void)
{
    CyU3PIoMatrixConfig_t io_cfg;
    CyU3PReturnStatus_t status = CY_U3P_SUCCESS;
    CyU3PSysClockConfig_t clkCfg;

        /* setSysClk400 clock configurations */
        clkCfg.setSysClk400 = CyTrue;   /* FX3 device's master clock is set to a frequency > 400 MHz */
        clkCfg.cpuClkDiv = 2;           /* CPU clock divider */
        clkCfg.dmaClkDiv = 2;           /* DMA clock divider */
        clkCfg.mmioClkDiv = 2;          /* MMIO clock divider */
        clkCfg.useStandbyClk = CyFalse; /* device has no 32KHz clock supplied */
        clkCfg.clkSrc = CY_U3P_SYS_CLK; /* Clock source for a peripheral block  */

    /* Initialize the device */
    status = CyU3PDeviceInit (&clkCfg);
    if (status != CY_U3P_SUCCESS)
    {
        goto handle_fatal_error;
    }

    /* Initialize the caches. Enable instruction cache and keep data cache disabled.
     * The data cache is useful only when there is a large amount of CPU based memory
     * accesses. When used in simple cases, it can decrease performance due to large 
     * number of cache flushes and cleans and also it adds to the complexity of the
     * code. */
    status = CyU3PDeviceCacheControl (CyTrue, CyFalse, CyFalse);
    if (status != CY_U3P_SUCCESS)
    {
        goto handle_fatal_error;
    }

    /* Configure the IO matrix for the device. On the FX3 DVK board, the COM port 
     * is connected to the IO(53:56). This means that either DQ32 mode should be
     * selected or lppMode should be set to UART_ONLY. Here we are choosing
     * UART_ONLY configuration for 16 bit slave FIFO configuration and setting
     * isDQ32Bit for 32-bit slave FIFO configuration. */
    io_cfg.useUart   = CyTrue;
    io_cfg.useI2C    = CyFalse;
    io_cfg.useI2S    = CyFalse;
    io_cfg.useSpi    = CyFalse;
#if (CY_FX_SLFIFO_GPIF_16_32BIT_CONF_SELECT == 0)
    io_cfg.isDQ32Bit = CyFalse;
    io_cfg.lppMode   = CY_U3P_IO_MATRIX_LPP_UART_ONLY;
#else
    io_cfg.isDQ32Bit = CyTrue;
    io_cfg.lppMode   = CY_U3P_IO_MATRIX_LPP_DEFAULT;
#endif
    /* No GPIOs are enabled. */
    io_cfg.gpioSimpleEn[0]  = 0;
    io_cfg.gpioSimpleEn[1]  = 0x08000000; /* GPIO 59 */
    io_cfg.gpioComplexEn[0] = 0;
    io_cfg.gpioComplexEn[1] = 0;
    status = CyU3PDeviceConfigureIOMatrix (&io_cfg);
    if (status != CY_U3P_SUCCESS)
    {
        goto handle_fatal_error;
    }

    /* This is a non returnable call for initializing the RTOS kernel */
    CyU3PKernelEntry ();

    /* Dummy return to make the compiler happy */
    return 0;

handle_fatal_error:

    /* Cannot recover from this error. */
    while (1);
}

/* [ ] */

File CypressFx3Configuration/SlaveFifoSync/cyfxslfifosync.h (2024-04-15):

/*
 ## Cypress USB 3.0 Platform header file (cyfxslfifosync.h)
 ## ===========================
 ##
 ##  Copyright Cypress Semiconductor Corporation, 2010-2011,
 ##  All Rights Reserved
 ##  UNPUBLISHED, LICENSED SOFTWARE.
 ##
 ##  CONFIDENTIAL AND PROPRIETARY INFORMATION
 ##  WHICH IS THE PROPERTY OF CYPRESS.
 ##
 ##  Use of this file is governed
 ##  by the license agreement included in the file
 ##
 ##     <install>/license/license.txt
 ##
 ##  where <install> is the Cypress software
 ##  installation root directory path.
 ##
 ## ===========================
*/

/* This file contains the constants and definitions used by the Slave FIFO application example */

#ifndef _INCLUDED_CYFXSLFIFOASYNC_H_
#define _INCLUDED_CYFXSLFIFOASYNC_H_

#include "cyu3externcstart.h"
#include "cyu3types.h"
#include "cyu3usbconst.h"


/* 16/32 bit GPIF Configuration select */
/* Set CY_FX_SLFIFO_GPIF_16_32BIT_CONF_SELECT = 0 for 16 bit GPIF data bus.
 * Set CY_FX_SLFIFO_GPIF_16_32BIT_CONF_SELECT = 1 for 32 bit GPIF data bus.
 */
#define CY_FX_SLFIFO_GPIF_16_32BIT_CONF_SELECT (1)
/* set up DMA channel for loopback/short packet/ZLP transfers */
//#define LOOPBACK_SHRT_ZLP

/* set up DMA channel for stream IN/OUT transfers */
#define STREAM_IN_OUT

/* set up MANUAL DMA channel for stream IN/OUT transfers */
#define MANUAL

#ifdef LOOPBACK_SHRT_ZLP
#define BURST_LEN 1
#define DMA_BUF_SIZE						  (1)
#define CY_FX_SLFIFO_DMA_BUF_COUNT_P_2_U      (4)              /* Slave FIFO P_2_U channel buffer count - Used with AUTO DMA channel */
#define CY_FX_SLFIFO_DMA_BUF_COUNT_U_2_P 	  (4)			   /* Slave FIFO U_2_P channel buffer count - Used with AUTO DMA channel */
#endif

#ifdef STREAM_IN_OUT
#define BURST_LEN 16
#define DMA_BUF_SIZE						 (16)
/* Slave FIFO P_2_U channel buffer count */
#define CY_FX_SLFIFO_DMA_BUF_COUNT_P_2_U      (2)
/* Slave FIFO U_2_P channel buffer count */
#define CY_FX_SLFIFO_DMA_BUF_COUNT_U_2_P 	  (10)
#endif

#define CY_FX_SLFIFO_DMA_BUF_COUNT      (2)                   /* Slave FIFO channel buffer count - This is used with MANUAL DMA channel */
#define CY_FX_SLFIFO_DMA_TX_SIZE        (0)	                  /* DMA transfer size is set to infinite */
#define CY_FX_SLFIFO_DMA_RX_SIZE        (0)	                  /* DMA transfer size is set to infinite */
#define CY_FX_SLFIFO_THREAD_STACK       (0x0400)              /* Slave FIFO application thread stack size */
#define CY_FX_SLFIFO_THREAD_PRIORITY    (8)                   /* Slave FIFO application thread priority */

/* Endpoint and socket definitions for the Slave FIFO application */

/* To change the Producer and Consumer EP enter the appropriate EP numbers for the #defines.
 * In the case of IN endpoints enter EP number along with the direction bit.
 * For eg. EP 6 IN endpoint is 0x86
 *     and EP 6 OUT endpoint is 0x06.
 * To change sockets mention the appropriate socket number in the #defines. */

/* Note: For USB 2.0 the endpoints and corresponding sockets are one-to-one mapped
         i.e. EP 1 is mapped to UIB socket 1 and EP 2 to socket 2 so on */

#define CY_FX_EP_PRODUCER               0x01    /* EP 1 OUT */
#define CY_FX_EP_CONSUMER               0x81    /* EP 1 IN */

#define CY_FX_PRODUCER_USB_SOCKET    CY_U3P_UIB_SOCKET_PROD_1    /* USB Socket 1 is producer */
#define CY_FX_CONSUMER_USB_SOCKET    CY_U3P_UIB_SOCKET_CONS_1    /* USB Socket 1 is consumer */


/* Used with FX3 Silicon. */
#define CY_FX_PRODUCER_PPORT_SOCKET    CY_U3P_PIB_SOCKET_0    /* P-port Socket 0 is producer */
#define CY_FX_CONSUMER_PPORT_SOCKET    CY_U3P_PIB_SOCKET_3    /* P-port Socket 3 is consumer */





/* Extern definitions for the USB Descriptors */
extern const uint8_t CyFxUSB20DeviceDscr[];
extern const uint8_t CyFxUSB30DeviceDscr[];
extern const uint8_t CyFxUSBDeviceQualDscr[];
extern const uint8_t CyFxUSBFSConfigDscr[];
extern const uint8_t CyFxUSBHSConfigDscr[];
extern const uint8_t CyFxUSBBOSDscr[];
extern const uint8_t CyFxUSBSSConfigDscr[];
extern const uint8_t CyFxUSBStringLangIDDscr[];
extern const uint8_t CyFxUSBManufactureDscr[];
extern const uint8_t CyFxUSBProductDscr[];

#include "cyu3externcend.h"

#endif /* _INCLUDED_CYFXSLFIFOASYNC_H_ */

/*[]*/
